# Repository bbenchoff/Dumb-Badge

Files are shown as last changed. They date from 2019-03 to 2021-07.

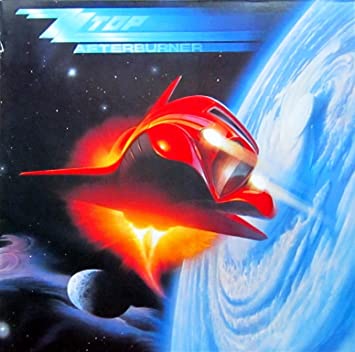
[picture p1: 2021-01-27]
Art-Assets/RandomGraphics/reference/Album Covers where guitars are spaceships/81FVQIFJtqL._SX355_.jpg

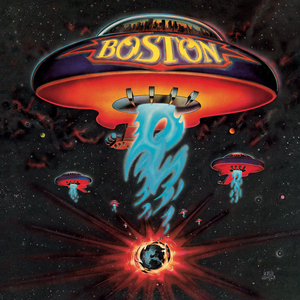
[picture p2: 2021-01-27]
Art-Assets/RandomGraphics/reference/Album Covers where guitars are spaceships/BostonBoston.jpg

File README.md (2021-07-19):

# VT-69 Portable Terminal

Front View Image

The VT-69 is a portable, battery-powered dumb terminal, along the lines of a VT-100, VT-220, Wyse WY-50, or other such microprocessor-controlled dumb terminals of the mid-80s to mid-90s. It's a portable shell, or a game console that only plays text-based adventures.

Features include:
* 4" LCD with 800x480 resolution
  * Display allows for a full 80x24 character display. *This is not a graphical display*. It will only display text characters.
  * 65536 colors, all of them.
* Silicone membrane keyboard
  * 69 keys. That's why it's the VT-69.
  * Custom-desinged, it's like the keypad on a remote control
  * Other keyboard layouts supported; DVORAK, QWERTZ, and AZERTY are simply a matter of keyboard legends.
* Battery power
  * Internal LiPo battery (> 2000 mAh) is charged from USB-C connector.
  * Provides > 12 hours of battery life.
* Microcontroller
  * ATSAMD51 clocked at blistering 120MHz
  * Custom software libraries allow for fastest text rendering possible	
* Connectivity
  * DE-9 RS-232 serial connector, provided with MAX3232
  * Serial output over USB-C connector
  * Internal UART connectors allow for internal connection to $Single Board Computer$ (a la VT-180) or any other development board with a 'standard' 40-pin header.
  * Hardware handshaking in both DE-9 RS-232 port and internal header
  * Supports _almost_ every terminal escape code recognized by the Linux console.
* Documentation
  * [Many pages of documentation](https://github.com/ViolenceWorks/VT-69/blob/main/Documentation/README.md)
  
Side View Image

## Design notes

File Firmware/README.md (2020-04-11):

## Install baremetal toolchain

`sudo apt-get install gcc-arm-none-eabi make git gcc libudev-dev`

[Download Microchip Advanced Software Framework](https://www.microchip.com/mymicrochip/filehandler.aspx?ddocname=en1000272) or you could [find the latest version here](https://www.microchip.com/mplab/avr-support/avr-and-sam-downloads-archive). Look for Advanced Software Framework (ASF) and grab the latest version. Unzip that somewhere.

This will allow you to compile the example program
\xdk-asf-3.48.0\sam0\applications\led_toggle\samd21_xplained_pro

Run make on that, should produce /samd21_xplained_pro/gcc/led_toggle_flash.bin

## Install edbg
[edbg](https://github.com/ataradov/edbg) is a tool for progamming ARM through Atmel edbg-based boards. Install that.

You can either clone it and do a `make all` or download the binary if you don't give a fuck about security.

This will produce a binary used to upload code

## Burn firmware

Test the led_toggle_flash.bin by uploading to SamD21 board with the following

`edbg -b -p -v -f led_toggle_flash.bin -t atmel_cm0p`

The toolchain and uploading has been verified on your machine. Now we need a makefile and such for the real code.

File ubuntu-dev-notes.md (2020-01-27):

Building Dumb Badge on Unbuntu -- for Idiots
===
```
sudo apt-get install gcc-arm-none-eabi binutils-arm-none-eabi gdb-arm-none-eabi openocd
```

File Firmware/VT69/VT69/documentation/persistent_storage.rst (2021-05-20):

Persistent Storage
==================

Persistent storage is middle-ware which provides means for storing data in non-volatile memory.

In terms of persistent storage stored data is called an item. Different items must have different IDs. IDs must be unique
and start with value of 1.
If an item is written two or more times, previous values get "overwritten" (read access returns the latest written data).

The usual use-case of persistent storage is an attempt to restore previously stored items on start-up.
For that, nv_storage_init function must be called. This function scans non-volatile memory starting from the given address
looking for items to restore. If there is a valid storage, the persistent storage initializes internal structures and gets
prepared for upcoming read (or write) accesses. If no valid storage found, the persistent storage tries to create one by
writing a header with storage information.

When an item is written the first item, it is being created inside the storage. In this case "offset" parameter is
ignored and the item is created with the given size. Re-sizing of items is not allowed, attempts to write more data than
item size or outside of an item (offset + size in write access is bigger than initial size) will fail.

Features
--------

* Power failure protection
* Wear-leveling
* Writing/reading parts of stored items
* Possibility to work with different types of non-volatile memory

Architecture and provided functionality
---------------------------------------

The persistent storage is composed of two layers:

* NV storage

This is the upper layer which contains implementation of wear-leveling, partial write and power failure protection
algorithms.

The partial write/read access allows to write/read parts of previously written items. For example, it is possible to read
first N bytes, or last N bytes, or N bytes from the middle of stored item.
Read operation always returns the latest successfully written data, it applies for partial write too. For example, if
partial write access stores M first bytes of the item of length of N (N > M), then read operation returns data that
contains M first bytes from partial write, and N-M last bytes from initial write.

The writing of an item or its part is split into three write accesses, after each it is validated whether the data was
written correctly by reading it out and comparing with the content of an item in RAM. It is required to be able to detect
whether data was written correctly if a power failure happens during writing procedure. This detection happens during
storage initialization (nv_storage_init function). In case of detection of invalid item, previous successfully written
item, if any, is used.

The area in non-volatile memory allocated for the persistent storage is split to at least (by default) two sectors.
Each write operation writes data to a new position in one of the sectors, gradually filling it up. When the sector is
full, the persistent storage can detect this fact during write/delete access. Upon detection, before actual write,
sector compression is performed. During the compression each of the stored items is gathered into one item (if there were
partial writes accesses) and copied to another sector. After all the items are copied, new sector is activated and
previous sector is erased.
The level of wearing non-volatile memory out can be tuned by adjusting the size of the area allocated for the persistent
storage.

Usually writing to non-volatile memory is a slow process, the sector compression may take significant time. The persistent
storage provides function (nv_storage_force_packing) to allow applications to perform the compression at the time suitable
for the application.

* Wrapper

This is the lower layer which is basically a wrapper between API expected by the upper layer and driver/middle-ware used
to work with non-volatile memory. At the moment, only internal flash on SAMD/SAML/SAMR/SAMC devices is supported.

Dependencies
------------

Flash driver on SAMD/SAML/SAMR/SAMC devices.

Limitations
-----------

Due to the architecture of the flash memory on SAMD/SAML/SAMR/SAMC devices, which allows only 8 writes before flash row
must be erase for the next write, each write of an item or a part of an item is aligned by 128 bytes.

Currently only internal flash memory on SAMD/SAML/SAMR/SAMC devices is supported.
It is user's responsibility to modify the linker script to reserve section in flash for the storage. Its start address
should match the address provided in the persistent storage configuration, its size should be equal to the sector size
multiplied by sectors amount (2 by default).

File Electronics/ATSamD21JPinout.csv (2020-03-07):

ATSAMD21J18A | Pin # | Function | ATSAMD21J | Pin # | Function
PA00 | 1 | XIN32 | PB00 | 61 | LCD 00
PA01 | 2 | XOUT32 | PB01 | 62 | LCD 01
PA02 | 3 | KEWROW0 | PB02 | 63 | LCD 02
PA03 | 4 | KEYROW01 | PB03 | 64 | LCD 03
PA04 | 13 | KEYROW02 | PB04 | 5 | LCD 04
PA05 | 14 | KEYROW03 | PB05 | 6 | LCD 05
PA06 | 15 | KEYROW04 | PB06 | 9 | LCD 06
PA07 | 16 | KEYROW05 | PB07 | 10 | LCD 07
PA08 | 17 | UART_TX | PB08 | 11 | LCD 08
PA09 | 18 | UART_RX | PB09 | 12 | LCD 09
PA10 | 19 | KEYROW06 | PB10 | 23 | LCD 10
PA11 | 20 | KEYROW07 | PB11 | 24 | LCD 11
PA12 | 29 | KEYROW08 | PB12 | 25 | LCD 12
PA13 | 30 | KEYROW09 | PB13 | 26 | LCD 13
PA14 | 31 |  | PB14 | 27 | LCD 14
PA15 | 32 |  | PB15 | 28 | LCD 15
PA16 | 35 | KEYCOLUMN0 | PB16 | 39 | LCD_RW
PA17 | 36 | KEYCOLUMN1 | PB17 | 40 | LCD_W/R
PA18 | 37 | KEYCOLUMN2
PA19 | 38 | KEYCOLUMN3
PA20 | 41 | KEYCOLUMN4
PA21 | 42 | KEYCOLUMN5
PA22 | 43 | SERCOM3 Pad0 | PB22 | 49 | LCD_CS
PA23 | 44 | SERCOM3 Pad1 | PB23 | 50 | LCD_D/C
PA24 | 45 | USB D-
PA25 | 46 | USB D+
PA27 | 51 | KEYCOLUMN6
PA28 | 53
PA30 | 57 | SWD Clock | PB30 | 59 | LCD_RST
PA31 | 58 | SWD data | PB31 | 60 | 3.3VFromPi

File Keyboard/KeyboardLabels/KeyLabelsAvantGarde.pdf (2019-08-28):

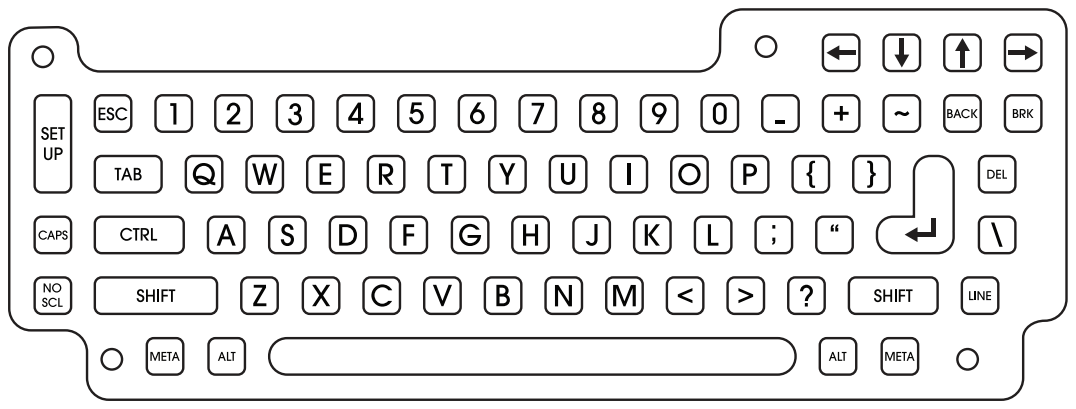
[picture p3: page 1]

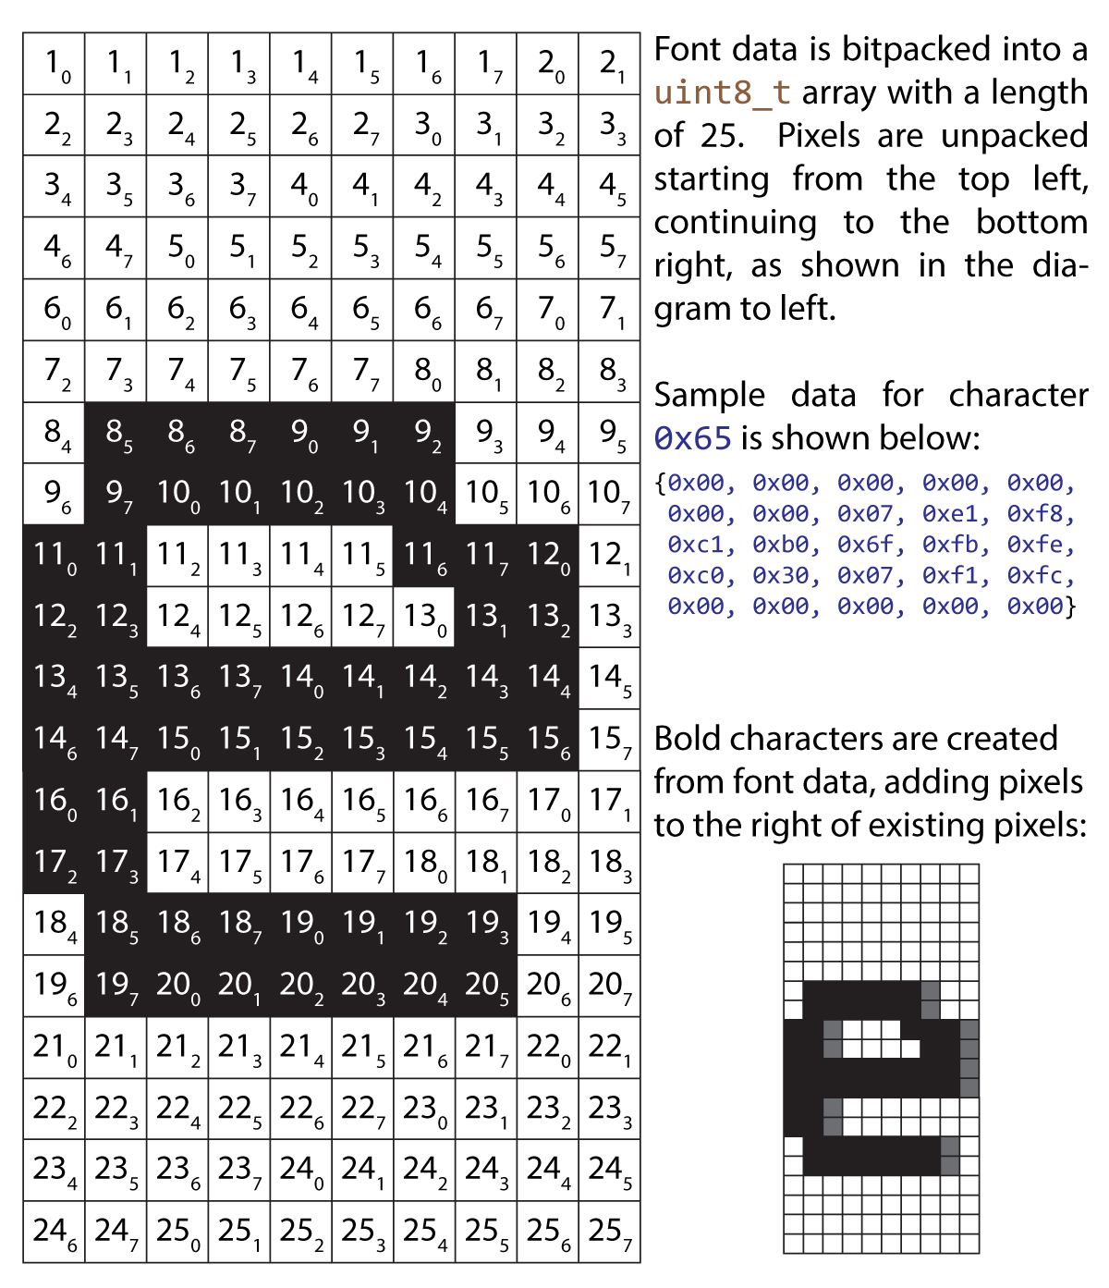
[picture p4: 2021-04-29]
Art-Assets/Documentation/FontDiagram.png

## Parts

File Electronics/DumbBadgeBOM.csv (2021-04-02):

Item # | Quantity | Reference Des. | Description / Value | MFG Part # | LCSC Part # | Package | Description | Pads | Qty |  | LABEL01 | LABEL02 | LABEL03 | LABEL04 | LABEL05 | LABEL06 | LABEL07 | LABEL08 | LABEL09 | LABEL10 | MANUFACTURER_NAME | MANUFACTURER_PART_NUMBER | MF | MOUSER_PART_NUMBER | MOUSER_PRICE-STOCK | MPN | OC_FARNELL | OC_NEWARK | POPULARITY | POPULATE | PROD_ID | SPICEPREFIX | TP_SIGNAL_NAME | URL | VALUE
1 | 1 | B1 | DNP | DNP | DNP | DNP | DNP
2 | 6 | C1, C4, C9, C22-24 | 0.1uF | C0805B104K500NT | C476766 | 0805-NO | 1ÂµF ceramic capacitors | 2 |  | 12 |  |  |  |  |  |  |  |  |  |  |  |  |  |  |  |  |  |  |  |  | CAP-08064 |  |  |  | 1.0uF
3 | 3 | C2, C7, C8, C14 | 10uF | CL21A106KPFNNNE | C17024 | 0805-NO | 1ÂµF ceramic capacitors | 2 |  | 6 |  |  |  |  |  |  |  |  |  |  |  |  |  |  |  |  |  |  |  |  | CAP-08064 |  |  |  | 1.0uF
4 | 1 | C3 | 2.2uF | GRM219R71C225KE15D | C86034 | 0805-NO | 1ÂµF ceramic capacitors | 2 |  | 2 |  |  |  |  |  |  |  |  |  |  |  |  |  |  |  |  |  |  |  |  | CAP-08064 |  |  |  | 1.0uF
5 | 4 | C5, C10, C11, C13 | 1.0uF | CL21B105KBFNNNE | C28323 | 0805-NO | 1ÂµF ceramic capacitors | 2 |  | 8 |  |  |  |  |  |  |  |  |  |  |  |  |  |  |  |  |  |  |  |  | CAP-08064 |  |  |  | 1.0uF
6 | 1 | C6 | 100uF | JMK325BJ107MM-T | C191180 | 1210 | CAPACITOR, American symbol | 2 |  | 2 |  |  |  |  |  |  |  |  |  |  |  |  |  |  |  |  |  |  | 6 |  |  | C
8 | 1 | C15 | 1uF | CL10A105KO8NNNC | C1592 | 0603-NO | Ceramic Capacitors | 2 |  | 2
9 | 10 | C16-C21, C25, C28-31 | .1u | 06035G104ZAT2A | C143639 | 0603-NO | Ceramic Capacitors | 2 |  | 20
10 | 2 | C26, C27 | 22pF | 0805CG220J500NT | C24658 | 0805-NO | 1ÂµF ceramic capacitors | 2 |  | 4 |  |  |  |  |  |  |  |  |  |  |  |  |  |  |  |  |  |  |  |  | CAP-08064 |  |  |  | 1.0uF
11 | 1 | D1 | MM3Z24VT1G | MM3Z24VT1G | C463816 | SOD323-W | DIODE | 3 |  | 3
12 | 1 | D2 | MBR0540 | MBR0540 | C232833 | SOD-123 | Diode | 3 |  | 3
13 | 1 | DE9FEMALE | DNP | EDGEMOUNTDE9 |  |  |  |  |  | 0
14 | 1 | FPC50CONN | 50PINFPC | Amphenol ICC / FCI 62684-501100ALF | C180244 | 62684-501100ALF |  | 52 |  | 52
15 | 1 | IC1 | ATSAMD51N19A-AU | ATSAMD51N19A-AU |  | QFP50P1600X1600X120-100N | ARM Microcontrollers - MCU 120MHZ 512KB FLASH 1 00 TQFP PKG 85C | 100 |  | 100 |  |  |  |  |  |  |  |  |  |  | Microchip | ATSAMD51N19A-AU |  | 556-ATSAMD51N19AAU | https://www.mouser.co.uk/ProductDetail/Microchip-Technology-Atmel/ATSAMD51N19A-AU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
16 | 1 | L1 | 6.8uH | TDK VLS5045EX-6R8M | C434837 | INDUCTOR_5X5MM_TDK_VLC5045 | Inductors | 2 |  | 2
17 | 1 | L2 | 6.8uH power L CID 2276 | Würth Elektronik 74404052068 |  | INDUCTOR_5X5MM_NR5040_NOTHERMALS | Inductors | 2 |  | 2
18 | 1 | L3 | 10uH | Taiyo Yuden CBC2518T100K | C271756 | INDUCTOR_1007 | Inductors | 2 |  | 2
19 | 3 | LED1, LED2, LED3 | LOW BATT | 17-21SURC/S530-A3/TR8 | C72037 | 0805-NO | LED | 2 |  | 6
20 | 2 | R1, R15 | 10k | 0603WAJ0103T5E | C15401 | 0603-NO | 1kÎ© resistor | 2 |  | 4 |  |  |  |  |  |  |  |  |  |  |  |  |  |  |  |  |  |  |  |  | RES-07856 |  |  |  | 1k
21 | 2 | R2, R3 | 5.1k | CR0603J5K10P05Z | C881139 | 0603-NO | 1kÎ© resistor | 2 |  | 4 |  |  |  |  |  |  |  |  |  |  |  |  |  |  |  |  |  |  |  |  | RES-07856 |  |  |  | 1k
22 | 2 | R4, R8 | 1.87M | 0603WAF1874T5E | C61679 | 0603-NO | 1kÎ© resistor | 2 |  | 4 |  |  |  |  |  |  |  |  |  |  |  |  |  |  |  |  |  |  |  |  | RES-07856 |  |  |  | 1k
23 | 1 | R5 | NCP21XW153J03RA | NCP21XW153J03RA | C152578 | 0805-NO | Resistors | 2 |  | 2
24 | 2 | R6, R13 | 200k | CQ03WAJ0204T5E | C966595 | 0603-NO | 1kÎ© resistor | 2 |  | 4 |  |  |  |  |  |  |  |  |  |  |  |  |  |  |  |  |  |  |  |  | RES-07856 |  |  |  | 1k
25 | 1 | R7 | 340k | 0603WAF3403T5E | C23143 | 0603-NO | 1kÎ© resistor | 2 |  | 2 |  |  |  |  |  |  |  |  |  |  |  |  |  |  |  |  |  |  |  |  | RES-07856 |  |  |  | 1k
26 | 1 | R9 | 270k | 0603WAJ0274T5E | C20088 | 0603-NO | 1kÎ© resistor | 2 |  | 2 |  |  |  |  |  |  |  |  |  |  |  |  |  |  |  |  |  |  |  |  | RES-07856 |  |  |  | 1k
27 | 2 | R10, R17 | 100k | 0603WAJ0104T5E | C15458 | 0603-NO | 1kÎ© resistor | 2 |  | 4 |  |  |  |  |  |  |  |  |  |  |  |  |  |  |  |  |  |  |  |  | RES-07856 |  |  |  | 1k
28 | 4 | R11, R14, R16, R20 | 1k | RC0603JR-071KL | C14676 | 0603-NO | 1kÎ© resistor | 2 |  | 8 |  |  |  |  |  |  |  |  |  |  |  |  |  |  |  |  |  |  |  |  | RES-07856 |  |  |  | 1k
29 | 1 | R12 | 6 Ohm | RC0603FR-076R04L | C482889 | 0603-NO | 1kÎ© resistor | 2 |  | 2 |  |  |  |  |  |  |  |  |  |  |  |  |  |  |  |  |  |  |  |  | RES-07856 |  |  |  | 1k
30 | 1 | SW1 | SPST_TACT-KMR2 | KMR221GLFS | C72443 | KMR2 | SMT 6mm switch, EVQQ2 series | 4 |  | 4
31 | 1 | T1 | MMUN2133LT1G | ON Semiconductor MMUN2133LT1G | C86182 | SC59-BEC | PNP Bias Resistor Transistor | 3 |  | 3
32 | 1 | U$5 | DNP | DNP |  | DNP |  |  |  | 0
33 | 1 | U$30 | DNP | DNP |  | DNP |  |  |  | 0
34 | 1 | U2 | TPS61090RSAR | Texas Instruments TPS61090RSAR | C206167 | PVQFN-16 | TPS6103x 4A Boost - 1.8-5.5V Input, Adjustable Output to 5.5V | 16 |  | 16
35 | 1 | U3 | MCP73871 | Microchip MCP73871-2CCI/ML | C511310 | QFN20_4MM | MCP73871 Lithium Polymer Battery Charger | 20 |  | 20
36 | 1 | U4 | FAN5333BSX | FAN5333BSX | C457660 | SOT23-5@1 | FAN5331 - LED/OLED 20V Boost Converter | 5 |  | 5
37 | 1 | U5 | TPD3E001SOT5 | TPD3E001DRLR | C470828 | SOT(5) |  | 5 |  | 5
38 | 1 | U6 | MAX3232 | MAX3232ECDR | C414613 | SO16 | RS232 Transceiver | 16 |  | 16 |  |  |  |  |  |  |  |  |  |  |  |  |  |  |  |  |  |  |  |  | IC-08171 |  |  |  | MAX3232
39 | 1 | USB | TYPE-C-31-M-12 | TYPE-C-31-M-12 | C165948 | TYPE-C-31-M-12 |  | 12 |  | 12
40 | 1 | VREG | REG1117 | REG1117A |  | SOT223 | 800mA and 1A Low Dropout (LDO) Positive Regulator | 4 |  | 4 |  |  |  |  |  |  |  |  |  |  |  |  |  |  |  | REG1117 | 1097566 | 14P6981 | 49
41 | 1 | X1 | NX3215SA-32.768K-STD-MUA-8 | S3132768092070 | C479190 | XTAL3215 | Low cost SMT crystals, no capacitors included | 2 |  | 2
42 | 1 | X2 | DNP | DNP |  | DNP | DUAL ROW STRAIGHT HEADER 1364 SERIES. 1.27mm x 1.27mm. Without Fixing Post. SMT |  |  | 0 |  |  |  |  |  |  |  |  |  |  |  |  |  |  |  |  | unknown | unknown
 |  |  |  |  |  |  |  |  |  | 0
 |  |  |  |  |  |  |  |  |  | 349

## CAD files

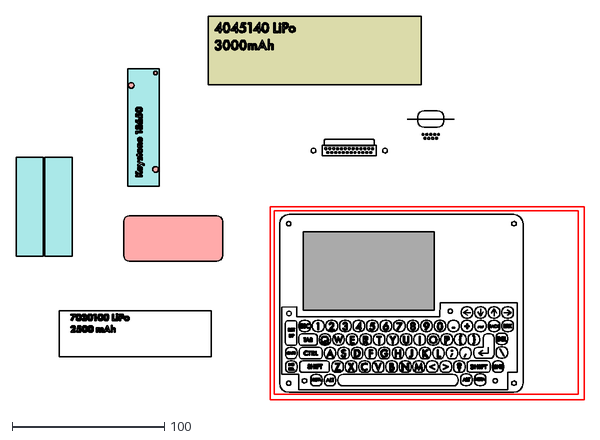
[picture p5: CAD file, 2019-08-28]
Keyboard/Vectors/SiliconeComplete.dxf
373.3 x 252.3

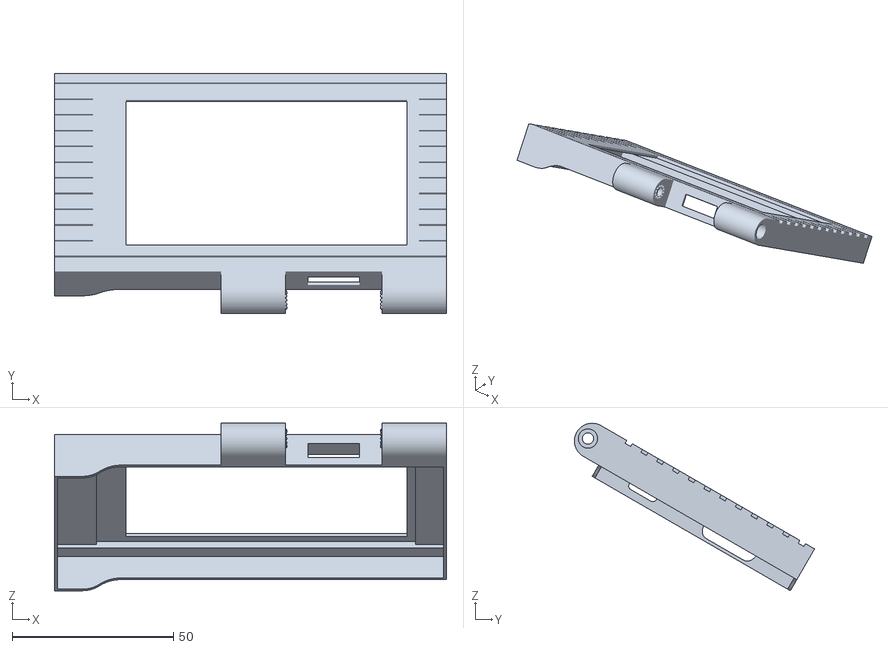
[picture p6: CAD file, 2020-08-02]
Extensions/FoldingKeyboardTest/ScreenHolder.stl
121.6 x 74.5 x 52.0

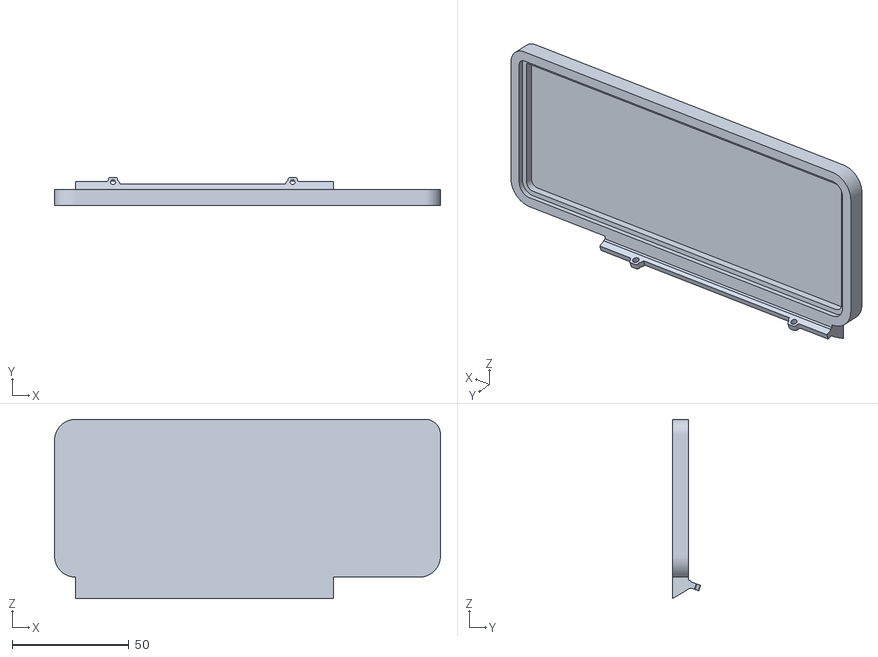
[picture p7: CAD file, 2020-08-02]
Extensions/MCUDemoBoard/KeyboardandMCU.stl
165.5 x 12.2 x 76.9

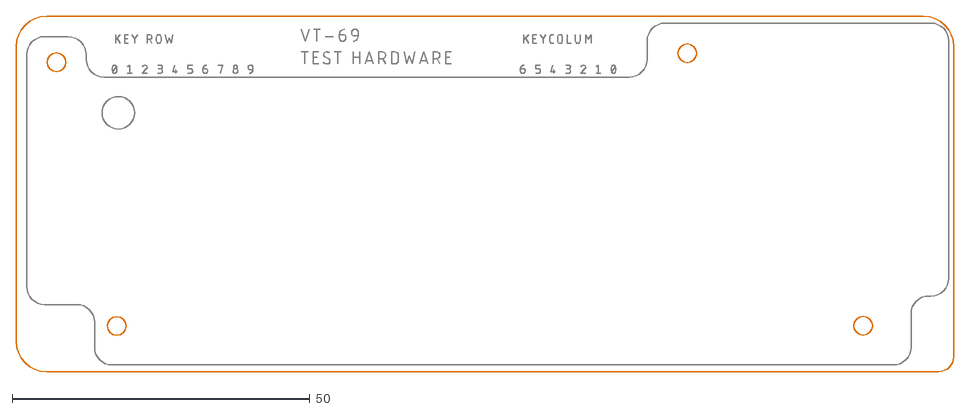
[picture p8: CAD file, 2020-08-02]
Extensions/TestKeyboard/Keyboard.dxf
157.5 x 59.7

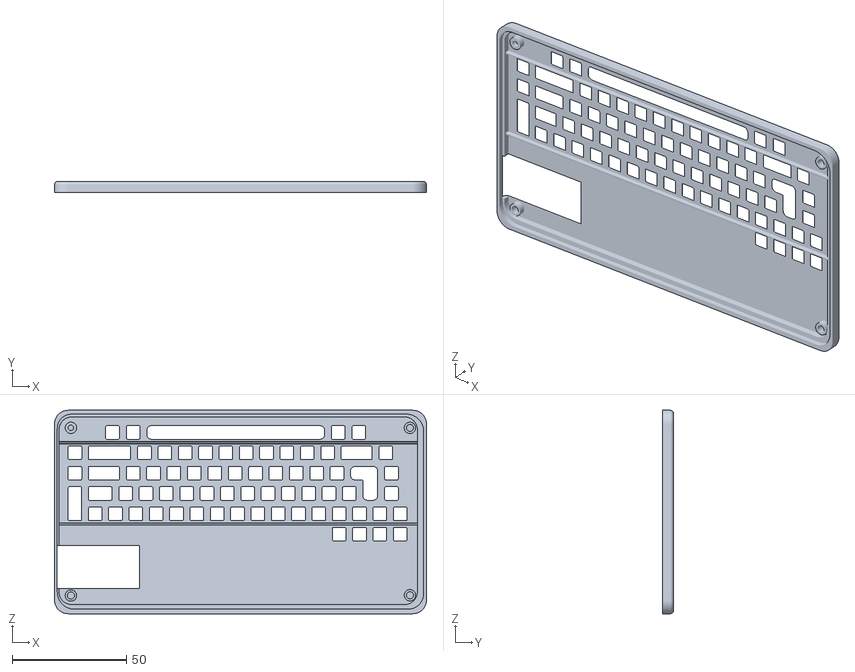
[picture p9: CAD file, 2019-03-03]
Keyboard/TestKeyboard/Hardware/KeyboardSTL.stl
162.6 x 5.00 x 88.9

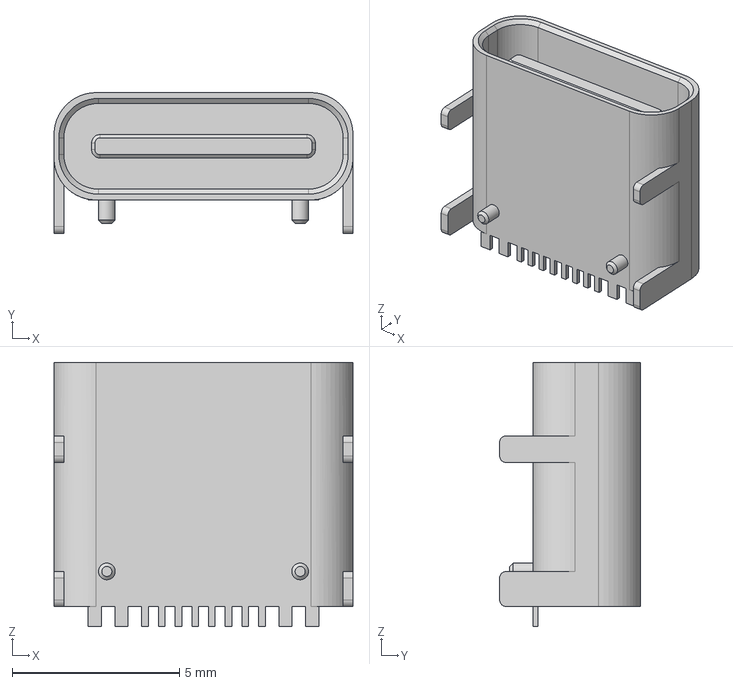
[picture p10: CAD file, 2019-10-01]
Mechanical/Models/HRO TYPE-C-31-M-12.step
8.94 x 4.21 x 7.90 mm

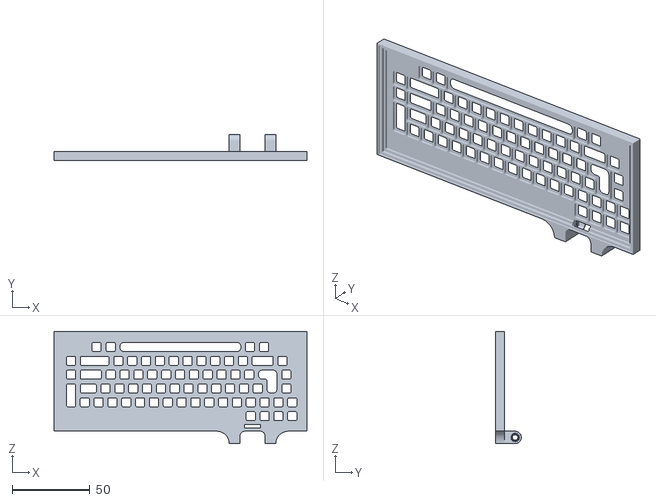
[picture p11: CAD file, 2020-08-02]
Extensions/FoldingKeyboardTest/Keyboard.stl
162.6 x 16.6 x 72.2

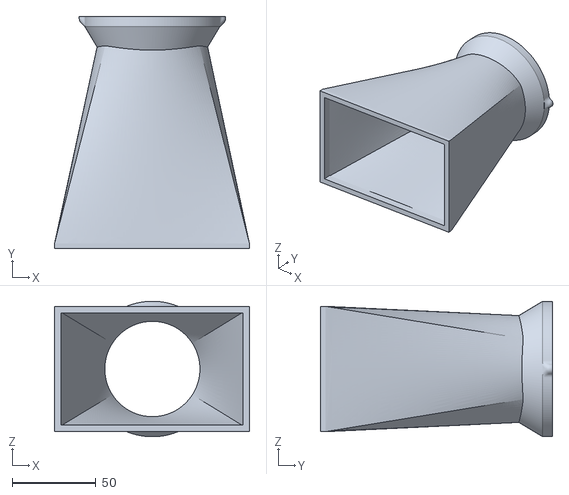
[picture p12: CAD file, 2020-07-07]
Extensions/MCUDemoBoard/CameraMountAdapter.stl
116.6 x 139.0 x 81.0

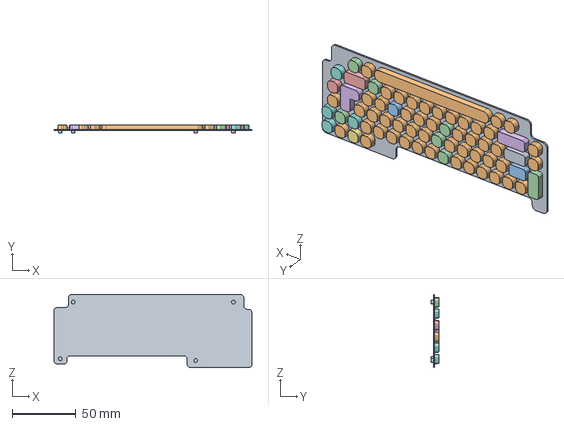
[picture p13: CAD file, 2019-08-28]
Mechanical/Models/Silicone Keyboard.step
154.9 x 6.50 x 57.1 mm

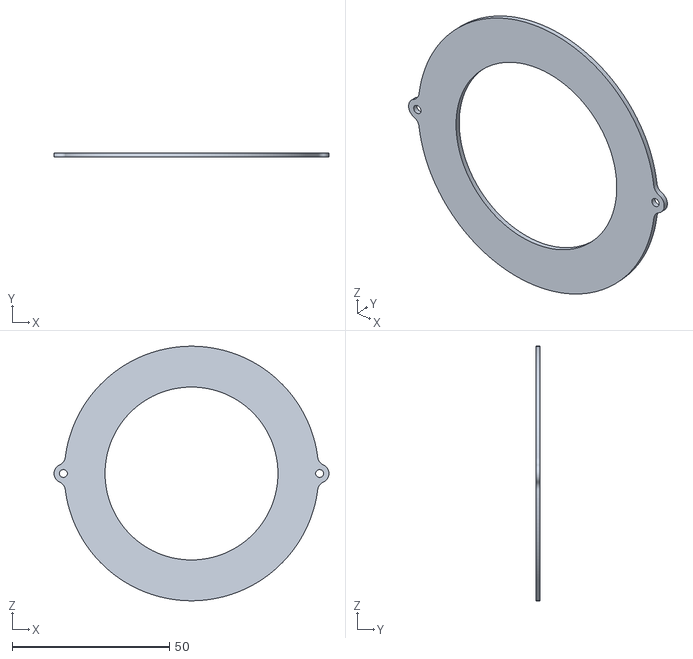
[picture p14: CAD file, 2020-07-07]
Extensions/MCUDemoBoard/CameraMountAdapterBack.stl
87.5 x 1.40 x 81.0

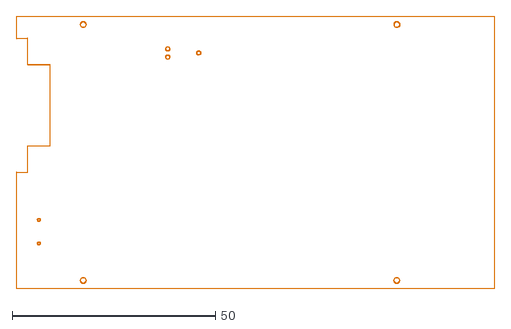
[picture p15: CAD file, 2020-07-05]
Extensions/MCUDemoBoard/MCUDemoBoard.dxf
117.8 x 67.2

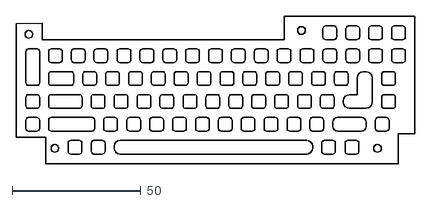
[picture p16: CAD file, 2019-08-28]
Keyboard/Vectors/SmallerSiliconeOutlineComposite.dxf
154.9 x 57.1

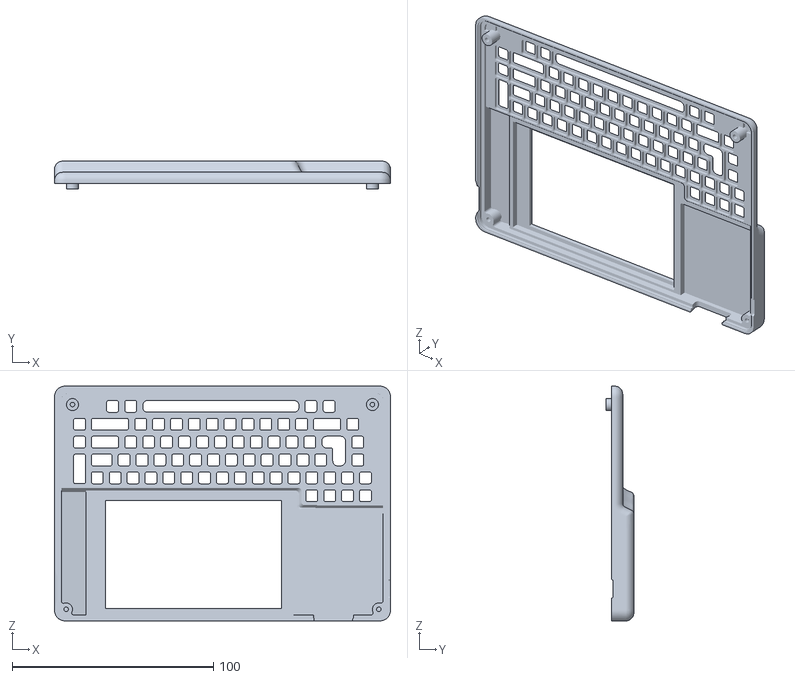
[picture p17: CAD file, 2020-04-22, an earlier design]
Mechanical/Top.stl
167.1 x 13.8 x 116.8

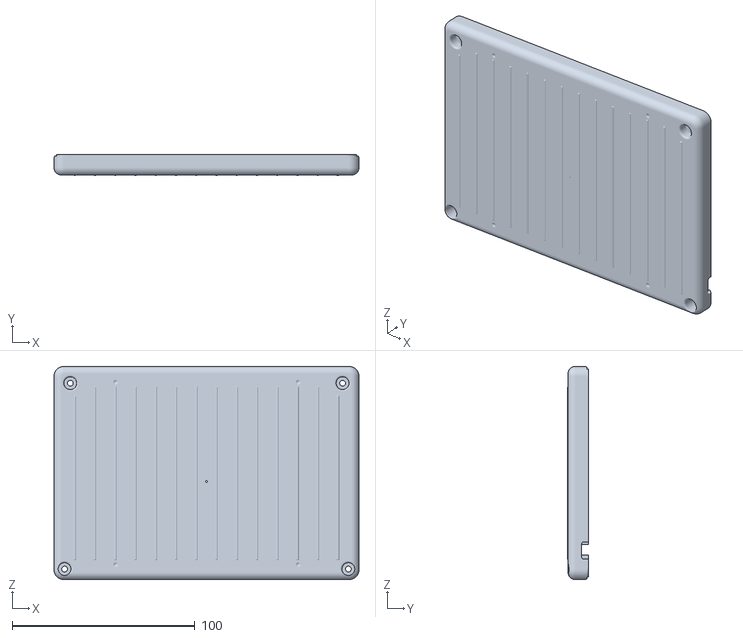
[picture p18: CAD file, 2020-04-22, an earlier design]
Mechanical/Bottom.stl
167.1 x 11.6 x 116.8

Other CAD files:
Keyboard/Vectors/DumbBadgeButtonsOutline.dxf
Keyboard/Vectors/DumbBadgeSiliconeOutline.dxf
Mechanical/Models/Bottom.stl
Mechanical/Models/Top.stl

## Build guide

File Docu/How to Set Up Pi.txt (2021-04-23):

1) first enable serial in raspi-update

blah blah blah just pick the option

2) edit the serial-getty service

sudo nano /lib/systemd/system/serial-getty@.service

change to this:

[Serivce]
ExecStart=-/sbin/agetty 9600 %I vt100

3) restart the systemctl

systemctl daemon-reload

---------------------------------------------------
ENABLE Shell messages on the serial console

from the console, type:
>sudo raspi-config

Select option P6, Serial Port

Select Yes. You would like a login shell to be accessible over serial.

2) edit the serial-getty service

> sudo nano /lib/systemd/system/serial-getty@.service

Change the line
> ExecStart=-/sbin/agetty -o '-p -- \\u' --keep-baud 115200,38400,9600 %I $TERM

to the following:

> ExecStart=-/sbin/agetty 9600 %I vt100

3) restart systemctl

> systemctl daemon-reload

4) reboot the system.

On reboot, you should see a stream of serial bits coming out of the GPIO pins. Eventually, you will be able to login

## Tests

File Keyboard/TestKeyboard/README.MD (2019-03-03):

This is the repo for the test/verification keyboard. It uses the same silicone keyboard, but *it's just a USB keyboard*

Included files are:

Firmware for Teensy LC
PCB for keyboard/Teensy LC
Plastic Bezel

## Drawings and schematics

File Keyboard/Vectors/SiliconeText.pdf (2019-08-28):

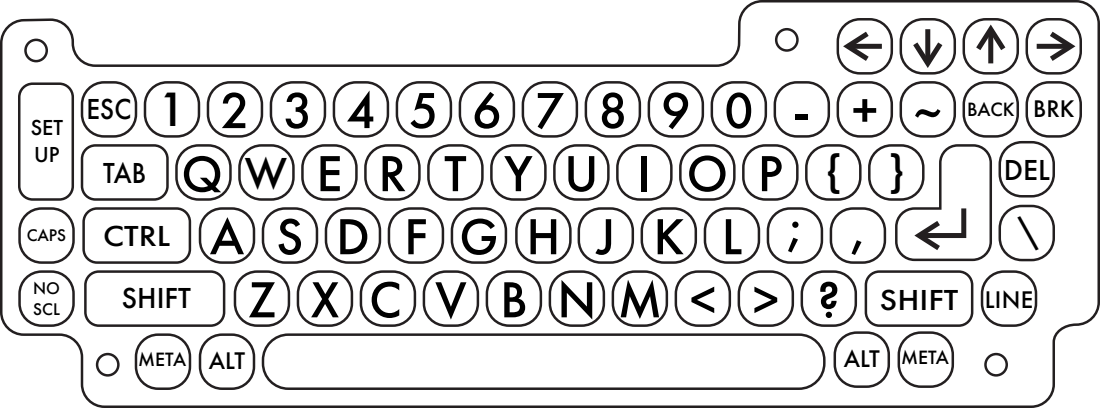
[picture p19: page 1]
1 2 3 4 5 6 7 8 9 0 - + ~ BACK; DEL \; TAB; CTRL A S D F G; SHIFT; Z X C V B N M < > ? SHIFT LINE; ESC; BRK; CAPS; NO SCL; SET UP; META ALT; ALT META

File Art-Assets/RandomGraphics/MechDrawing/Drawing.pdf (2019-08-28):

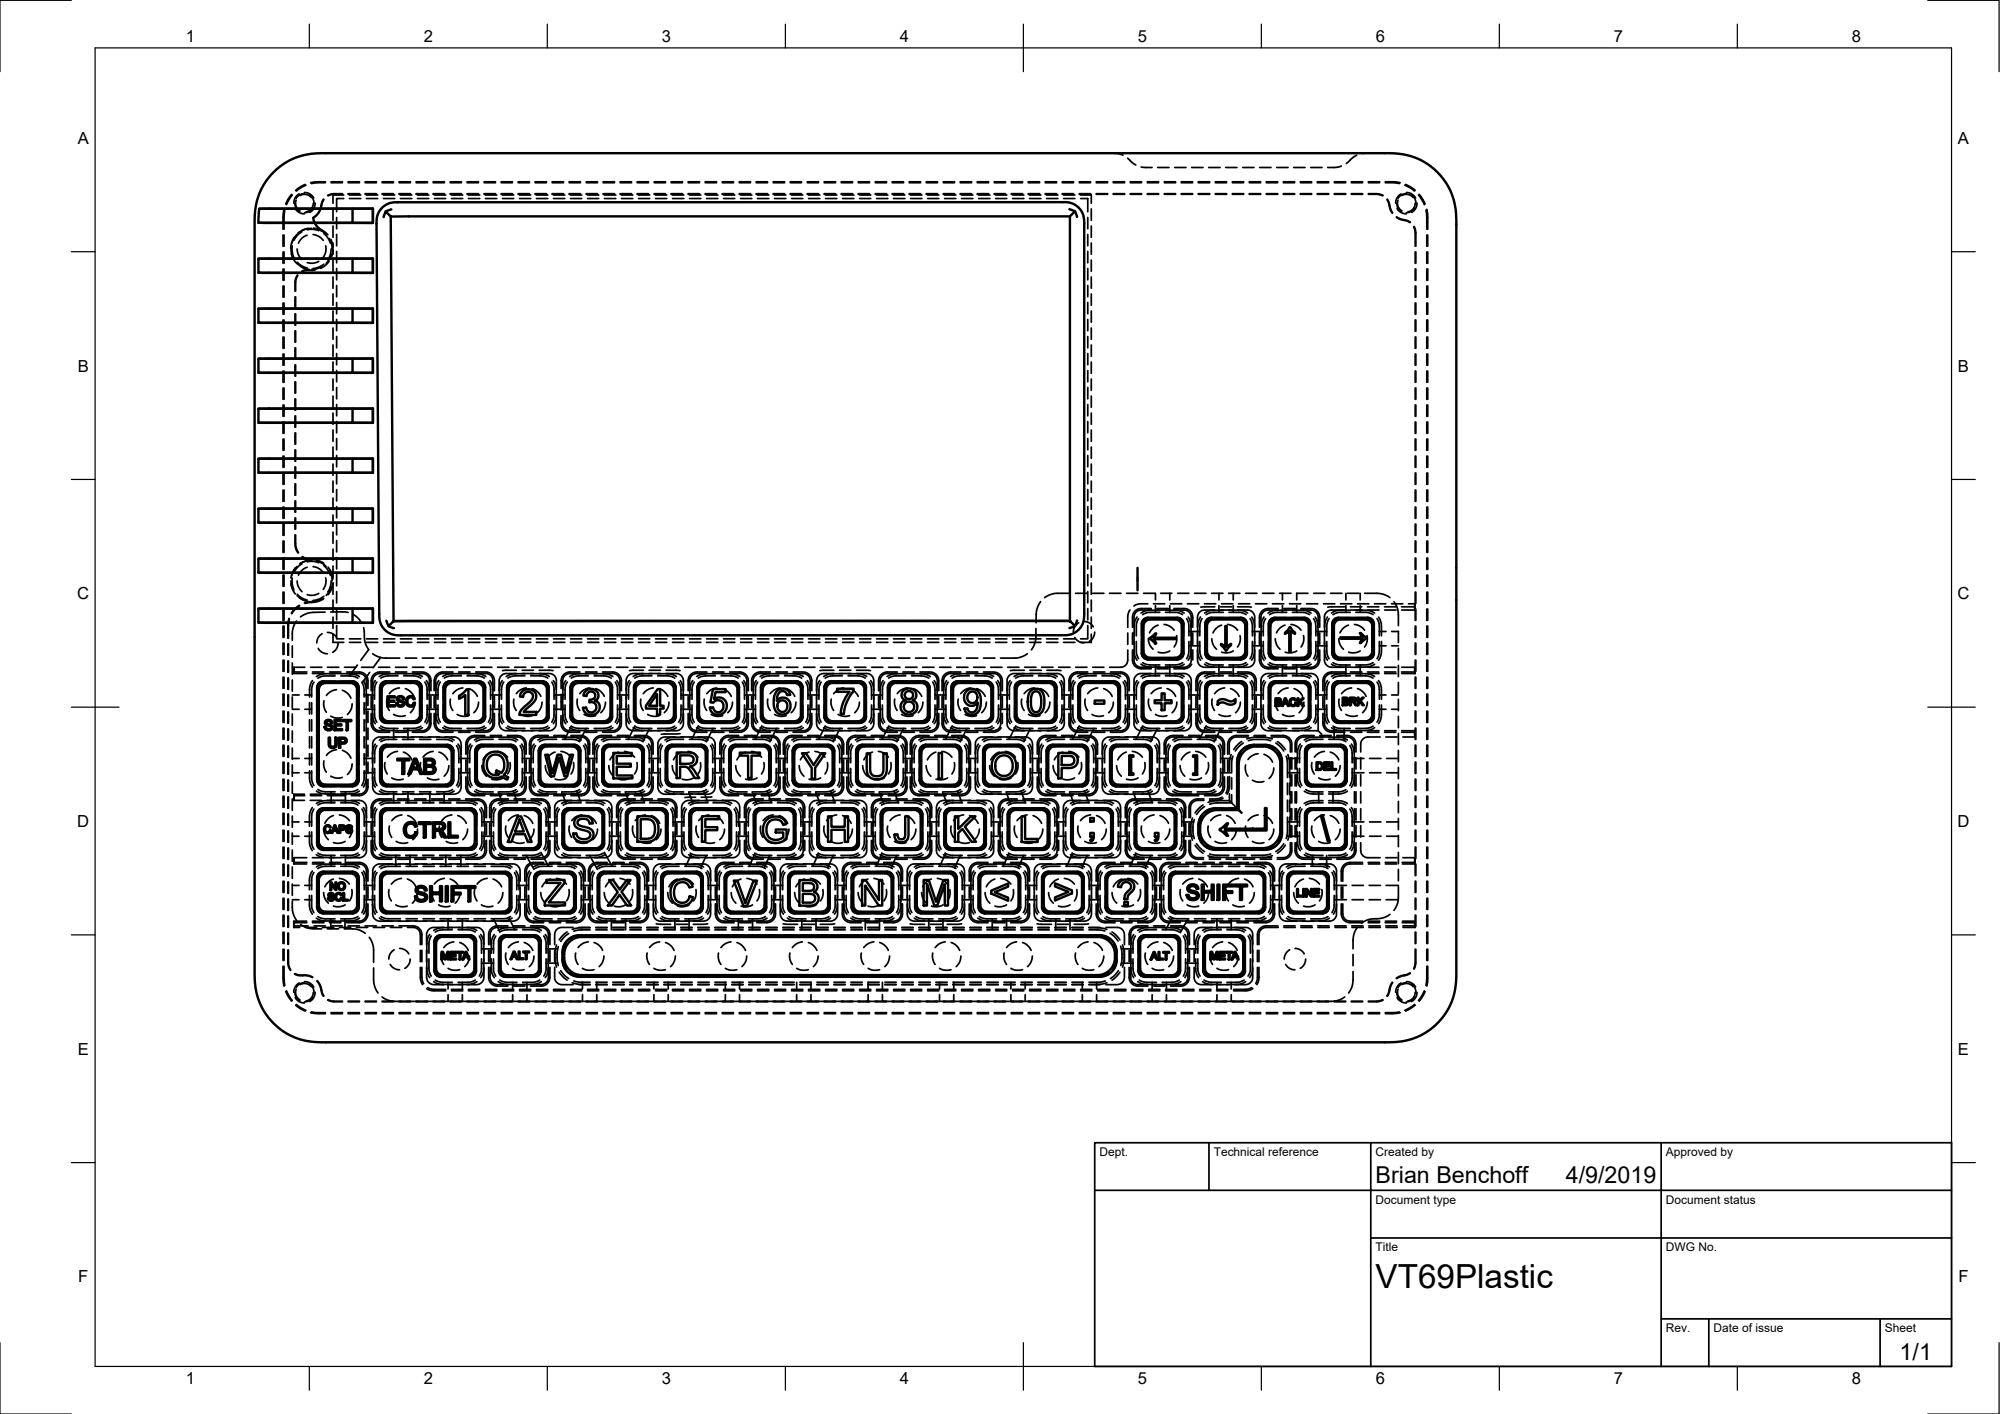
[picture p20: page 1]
Dept.; Technical reference; Created by; Approved by; Document type; Document status; Title; DWG No.; Rev.; Date of issue; Sheet; Brian Benchoff

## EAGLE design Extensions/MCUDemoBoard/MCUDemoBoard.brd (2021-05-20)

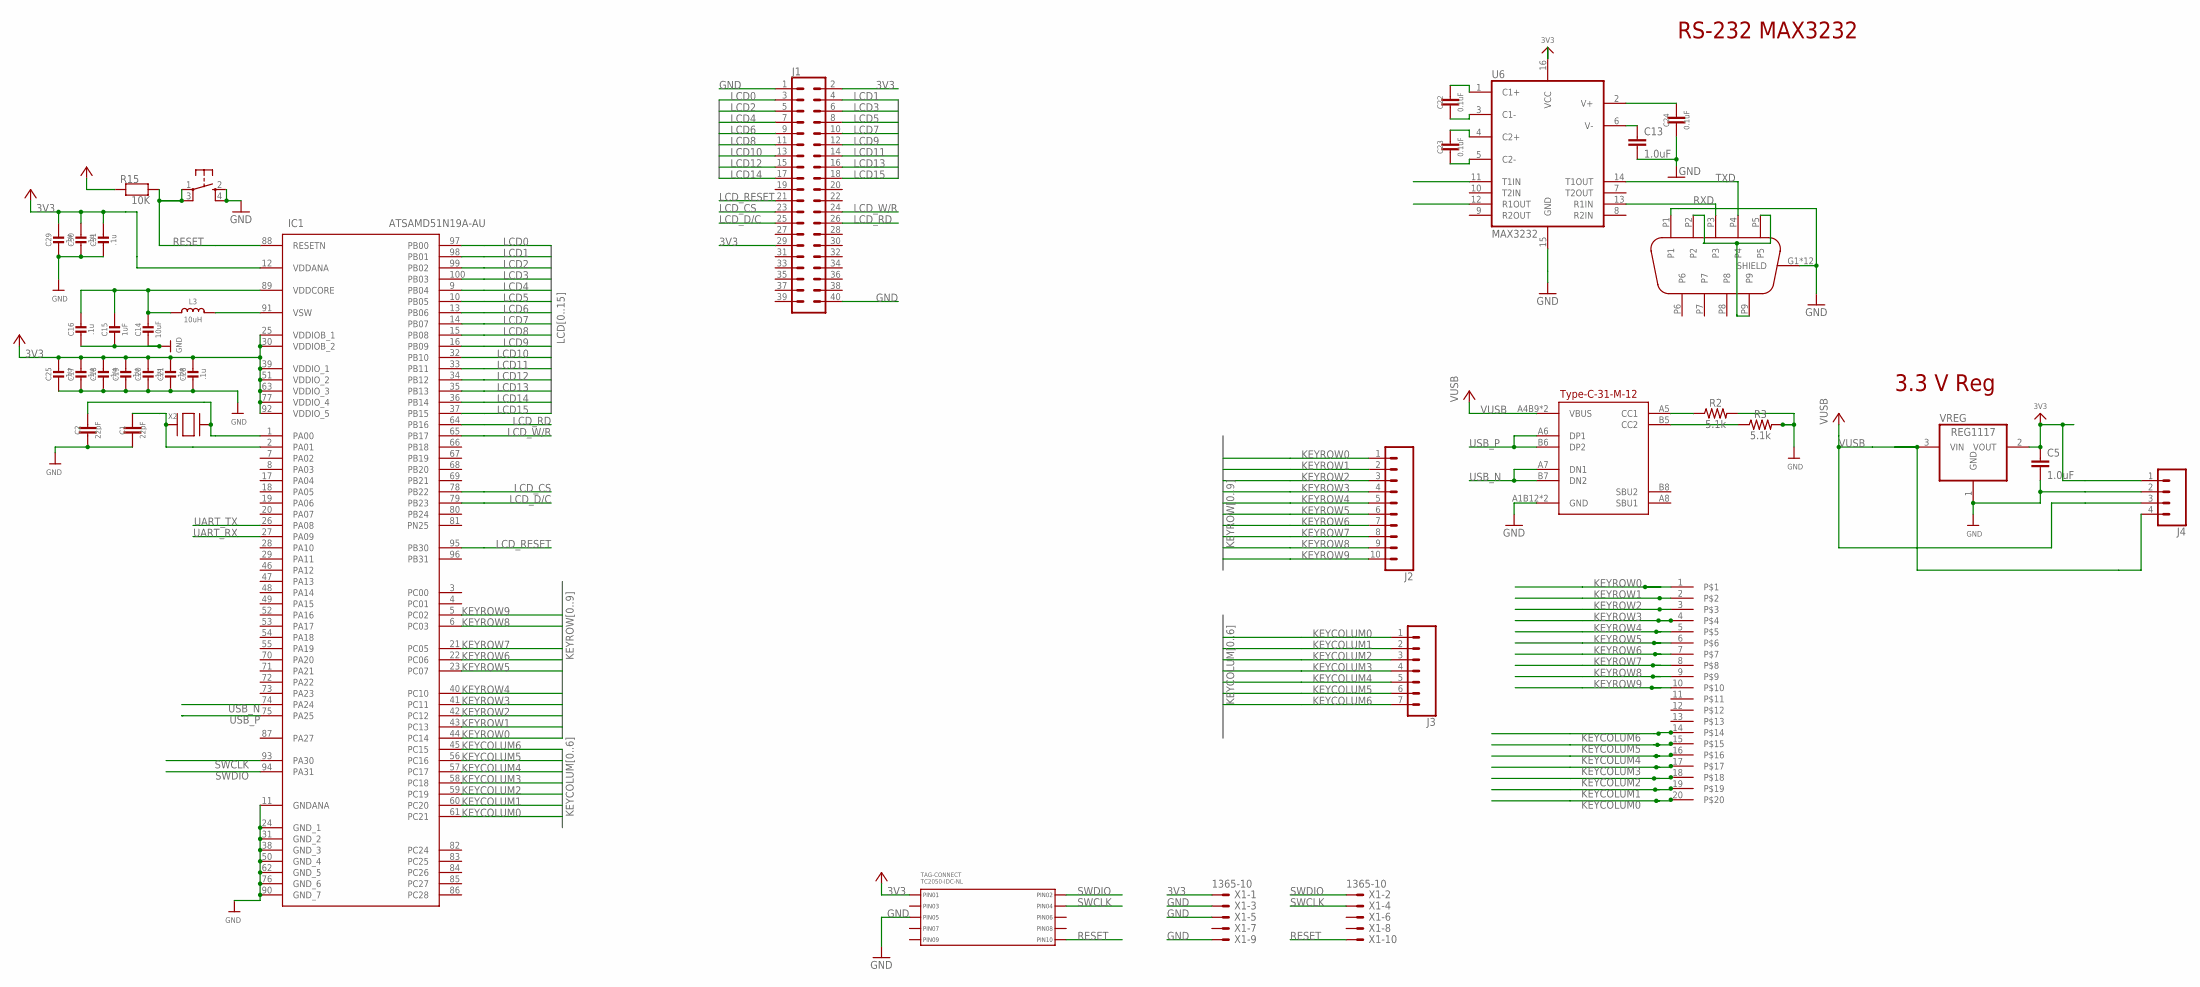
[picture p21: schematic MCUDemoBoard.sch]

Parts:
C1, C2: 22pF; 0805
C5, C13: 1.0uF; 0805
C14: 10uF; 0805-NO
C15: 1uF; 0603-NO
C16, C17, C18, C19, C20, C21, C25, C28, C29, C30, C31: .1u; 0603-NO
C22, C23, C24: 0.1uF; 0805
DE9FEMALE: EDGEMOUNTDE9; DE09S065TLF
IC1: ATSAMD51N19A-AU; QFP50P1600X1600X120-100N
J1: CONN_20X2NOSILK; 2X20_NOSILK
J2: CONN_10NO_SILK_PTH_FEMALE; 1X10_NO_SILK
J3: CONN_07NO_SILK; 1X07_NO_SILK
J4: CONN_04; 1X04
L3: 10uH; INDUCTOR_1007
R2, R3: 5.1k; 0603
R15: 10K; 0603-NO
SW2: SPST_TACT-KMR2; KMR2
TAG-CONNECT: TC2050-IDC-NL
U6: MAX3232; SO16
U$1: FC1-20-L2-T-WT20PIN; FC1-20-L2-T-WT
USB: TYPE-C-31-M-12
VREG: REG1117; SOT223
X1: 1365-10
X2: NX3215SA-32.768K-STD-MUA-8; XTAL3215

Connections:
3V3: C5.1, C17.2, C18.2, C19.2, C20.2, C21.2, C25.2, C28.2, C29.2, C30.2, C31.2, IC1.12 (VDDANA), IC1.25 (VDDIOB_1), IC1.30 (VDDIOB_2), IC1.39 (VDDIO_1), IC1.51 (VDDIO_2), IC1.63 (VDDIO_3), IC1.77 (VDDIO_4), IC1.92 (VDDIO_5), J1.2, J1.29, J4.1, R15.1, TAG-CONNECT.P$1 (PIN1), U6.16 (VCC), VREG.2 (VOUT), X1.1
GND: C1.1, C2.1, C5.2, C13.2, C14.2, C15.2, C16.1, C17.1, C18.1, C19.1, C20.1, C21.1, C24.2, C25.1, C28.1, C29.1, C30.1, C31.1, DE9FEMALE.G1 (SHIELD), DE9FEMALE.G2 (SHIELD), DE9FEMALE.G3 (SHIELD), DE9FEMALE.G4 (SHIELD), DE9FEMALE.G5 (SHIELD), DE9FEMALE.G6 (SHIELD), DE9FEMALE.G7 (SHIELD), DE9FEMALE.G8 (SHIELD), DE9FEMALE.G9 (SHIELD), DE9FEMALE.G10 (SHIELD), DE9FEMALE.G11 (SHIELD), DE9FEMALE.G12 (SHIELD), DE9FEMALE.P1, IC1.11 (GNDANA), IC1.24 (GND_1), IC1.31 (GND_2), IC1.38 (GND_3), IC1.50 (GND_4), IC1.62 (GND_5), IC1.76 (GND_6), IC1.90 (GND_7), J1.1, J1.40, J4.2, R2.2, R3.2, SW2.2 (S), SW2.4 (S1), TAG-CONNECT.P$5 (PIN5), U6.15 (GND), USB.A1B12 (GND), USB.B1A12 (GND), VREG.1 (GND), X1.3, X1.5, X1.9
KEYCOLUM0: IC1.61 (PC21), J3.1, U$1.20
KEYCOLUM1: IC1.60 (PC20), J3.2, U$1.19
KEYCOLUM2: IC1.59 (PC19), J3.3, U$1.18
KEYCOLUM3: IC1.58 (PC18), J3.4, U$1.17
KEYCOLUM4: IC1.57 (PC17), J3.5, U$1.16
KEYCOLUM5: IC1.56 (PC16), J3.6, U$1.15
KEYCOLUM6: IC1.45 (PC15), J3.7, U$1.14
KEYROW0: IC1.44 (PC14), J2.1, U$1.1
KEYROW1: IC1.43 (PC13), J2.2, U$1.2
KEYROW2: IC1.42 (PC12), J2.3, U$1.3
KEYROW3: IC1.41 (PC11), J2.4, U$1.4
KEYROW4: IC1.40 (PC10), J2.5, U$1.5
KEYROW5: IC1.23 (PC07), J2.6, U$1.6
KEYROW6: IC1.22 (PC06), J2.7, U$1.7
KEYROW7: IC1.21 (PC05), J2.8, U$1.8
KEYROW8: IC1.6 (PC03), J2.9, U$1.9
KEYROW9: IC1.5 (PC02), J2.10, U$1.10
LCD0: IC1.97 (PB00), J1.3
LCD1: IC1.98 (PB01), J1.4
LCD2: IC1.99 (PB02), J1.5
LCD3: IC1.100 (PB03), J1.6
LCD4: IC1.9 (PB04), J1.7
LCD5: IC1.10 (PB05), J1.8
LCD6: IC1.13 (PB06), J1.9
LCD7: IC1.14 (PB07), J1.10
LCD8: IC1.15 (PB08), J1.11
LCD9: IC1.16 (PB09), J1.12
LCD10: IC1.32 (PB10), J1.13
LCD11: IC1.33 (PB11), J1.14
LCD12: IC1.34 (PB12), J1.15
LCD13: IC1.35 (PB13), J1.16
LCD14: IC1.36 (PB14), J1.17
LCD15: IC1.37 (PB15), J1.18
LCD_CS: IC1.78 (PB22), J1.23
LCD_D/C: IC1.79 (PB23), J1.25
LCD_RD: IC1.64 (PB16), J1.26
LCD_RESET: IC1.95 (PB30), J1.21
LCD_W/R: IC1.65 (PB17), J1.24
unnamed: C24.1, U6.2 (V+)
unnamed: C2.2, IC1.1 (PA00), X2.P$1
unnamed: C1.2, IC1.2 (PA01), X2.P$2
unnamed: C22.2, U6.3 (C1-)
unnamed: C22.1, U6.1 (C1+)
unnamed: C23.1, U6.4 (C2+)
unnamed: C23.2, U6.5 (C2-)
unnamed: C13.1, U6.6 (V-)
unnamed: DE9FEMALE.P2, DE9FEMALE.P5, DE9FEMALE.P9
unnamed: R2.1, USB.A5 (CC1)
unnamed: R3.1, USB.B5 (CC2)
unnamed: C14.1, C15.1, C16.2, IC1.89 (VDDCORE), L3.P$1 (1)
unnamed: IC1.91 (VSW), L3.P$2 (2)
RESET: IC1.88 (RESETN), R15.2, SW2.1, SW2.3 (P1), TAG-CONNECT.P$10 (PIN10), X1.10
RXD: DE9FEMALE.P3, U6.13 (R1IN)
SWCLK: IC1.93 (PA30), TAG-CONNECT.P$4 (PIN4), X1.4
SWDIO: IC1.94 (PA31), TAG-CONNECT.P$2 (PIN2), X1.2
TXD: DE9FEMALE.P4, U6.14 (T1OUT)
UART_RX: IC1.27 (PA09), U6.12 (R1OUT)
UART_TX: IC1.26 (PA08), U6.11 (T1IN)
USB_N: IC1.74 (PA24), USB.A7 (DN1), USB.B7 (DN2)
USB_P: IC1.75 (PA25), USB.A6 (DP1), USB.B6 (DP2)
VUSB: J4.3, J4.4, USB.A4B9 (VBUS), USB.B4A9 (VBUS), VREG.3 (VIN)

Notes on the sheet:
RS-232 MAX3232
Type-C-31-M-12
3.3 V Reg

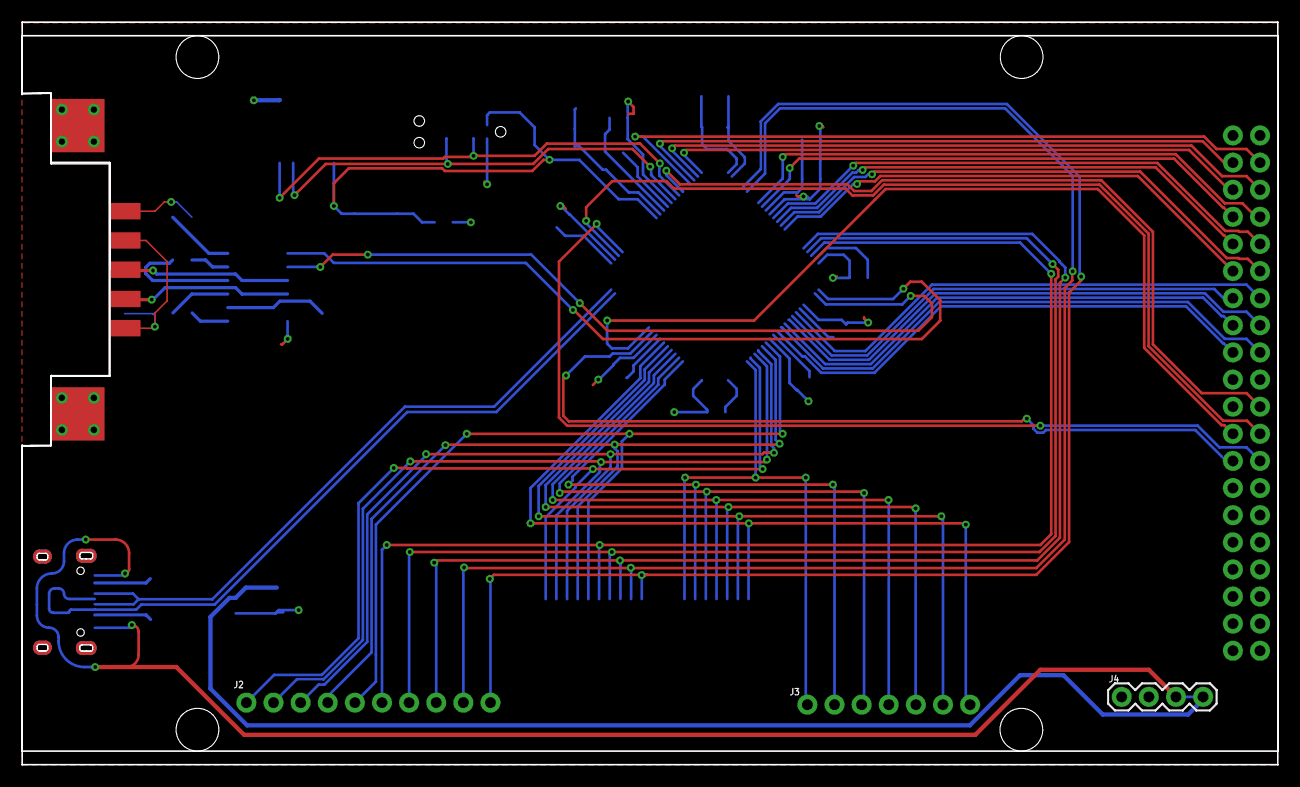
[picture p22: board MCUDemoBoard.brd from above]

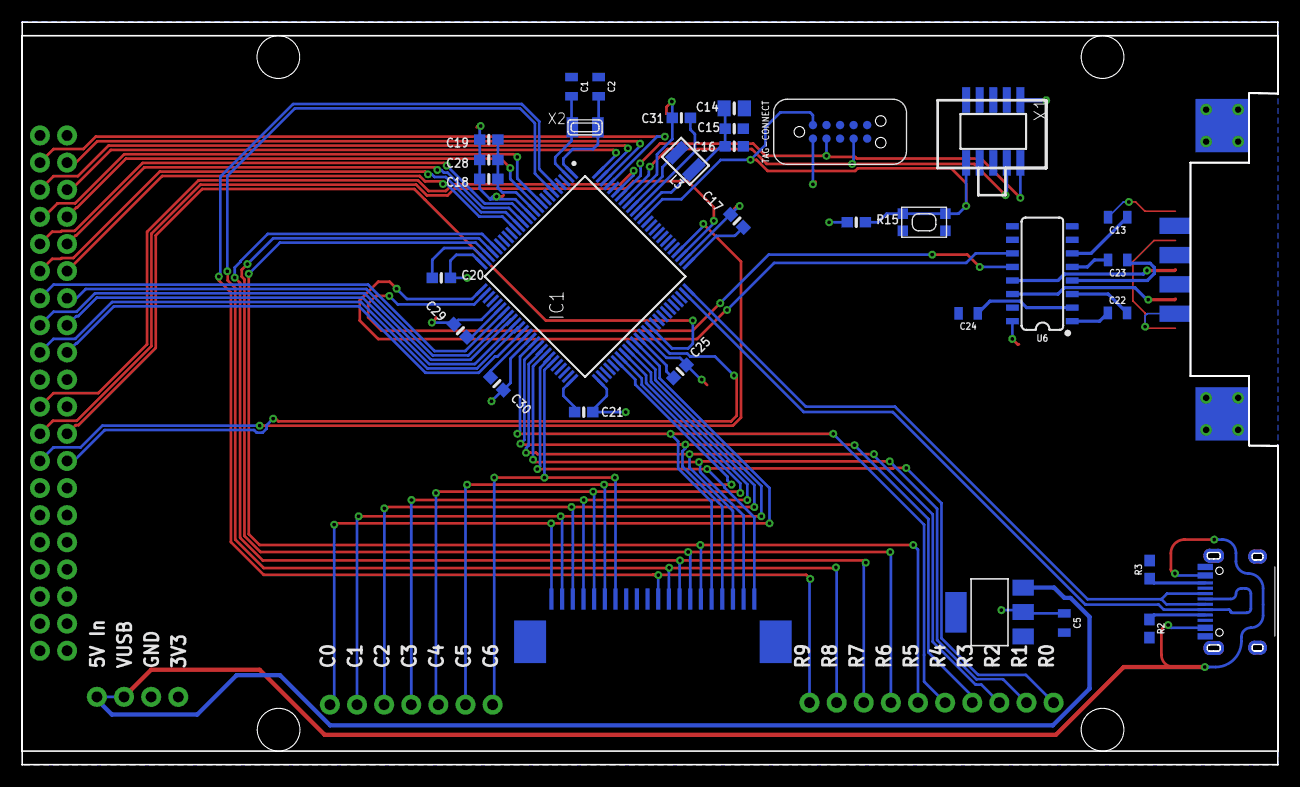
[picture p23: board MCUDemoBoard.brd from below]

Board: 2 copper layers, 117.6 x 69.5 mm, 38 parts (34 on the bottom side), 63 nets.

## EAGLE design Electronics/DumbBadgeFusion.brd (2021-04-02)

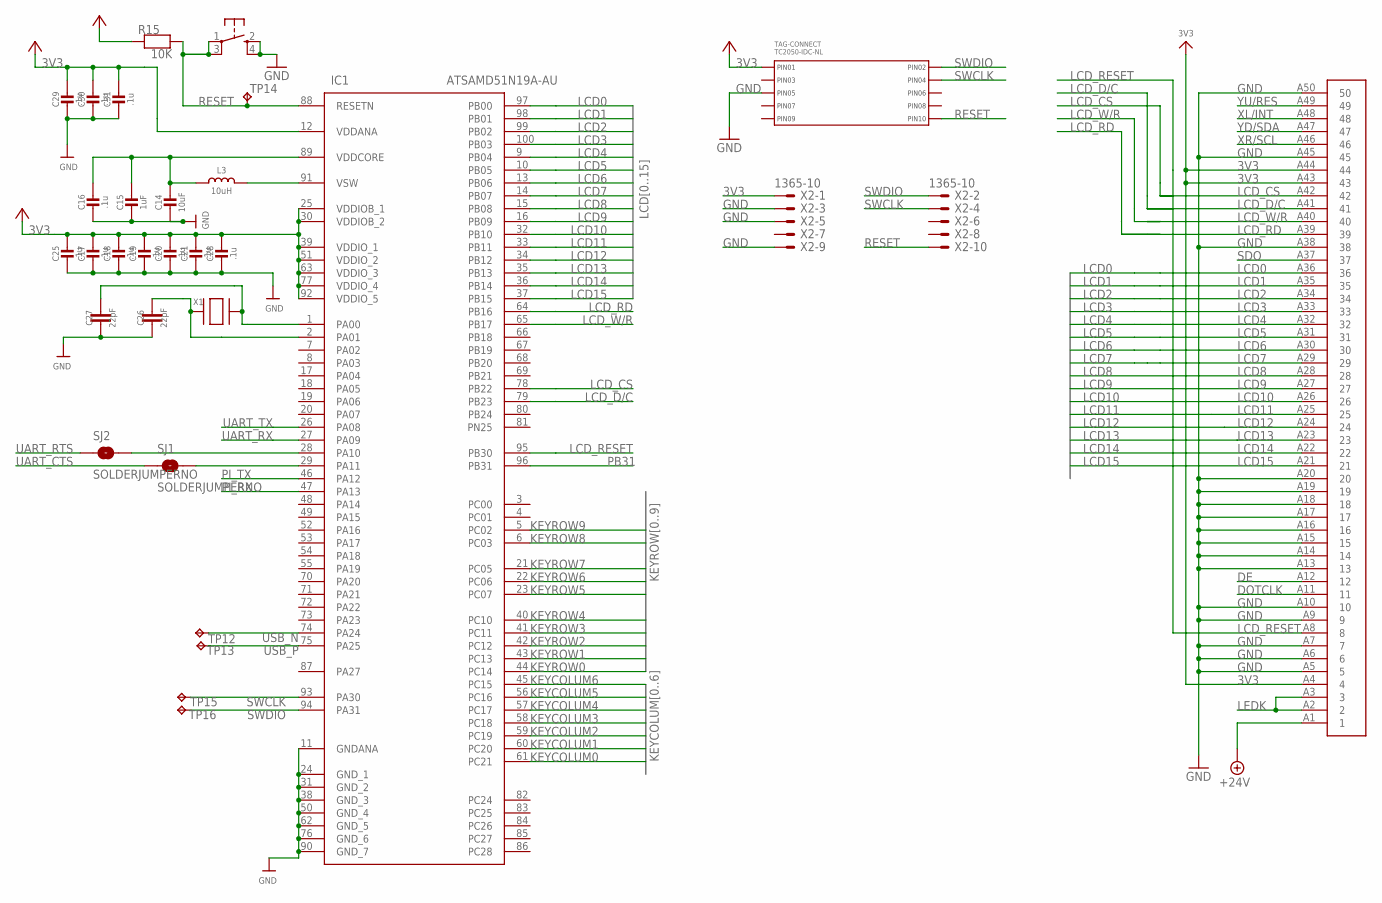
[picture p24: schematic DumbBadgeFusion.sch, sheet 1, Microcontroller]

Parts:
C14: 10uF; 0805-NO
C15: 1uF; 0603-NO
C16, C17, C18, C19, C20, C21, C25, C28, C29, C30, C31: .1u; 0603-NO
C26, C27: 22pF; 0805
FPC50CONN: 50PINFPC; 62684-501100ALF
IC1: ATSAMD51N19A-AU; QFP50P1600X1600X120-100N
L3: 10uH; INDUCTOR_1007
R15: 10K; 0603-NO
SJ1, SJ2: SOLDERJUMPERNO; SJ_2S-NO
SW1: SPST_TACT-KMR2; KMR2
TAG-CONNECT: TC2050-IDC-NL
TP12, TP13, TP14, TP15, TP16: TPB1,27; B1,27
X1: NX3215SA-32.768K-STD-MUA-8; XTAL3215
X2: 1365-10

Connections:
3V3: C17.2, C18.2, C19.2, C20.2, C21.2, C25.2, C28.2, C29.2, C30.2, C31.2, FPC50CONN.A4 (4), FPC50CONN.A43 (43), FPC50CONN.A44 (44), IC1.12 (VDDANA), IC1.25 (VDDIOB_1), IC1.30 (VDDIOB_2), IC1.39 (VDDIO_1), IC1.51 (VDDIO_2), IC1.63 (VDDIO_3), IC1.77 (VDDIO_4), IC1.92 (VDDIO_5), R15.1, TAG-CONNECT.P$1 (PIN1), X2.1; also elsewhere on the board
+24V: FPC50CONN.A1 (1); also elsewhere on the board
DE: FPC50CONN.A12 (12)
DOTCLK: FPC50CONN.A11 (11)
GND: C14.2, C15.2, C16.1, C17.1, C18.1, C19.1, C20.1, C21.1, C25.1, C26.1, C27.1, C28.1, C29.1, C30.1, C31.1, FPC50CONN.A5 (5), FPC50CONN.A6 (6), FPC50CONN.A7 (7), FPC50CONN.A9 (9), FPC50CONN.A10 (10), FPC50CONN.A13 (13), FPC50CONN.A14 (14), FPC50CONN.A15 (15), FPC50CONN.A16 (16), FPC50CONN.A17 (17), FPC50CONN.A18 (18), FPC50CONN.A19 (19), FPC50CONN.A20 (20), FPC50CONN.A38 (38), FPC50CONN.A45 (45), FPC50CONN.A50 (50), IC1.11 (GNDANA), IC1.24 (GND_1), IC1.31 (GND_2), IC1.38 (GND_3), IC1.50 (GND_4), IC1.62 (GND_5), IC1.76 (GND_6), IC1.90 (GND_7), SW1.2 (S), SW1.4 (S1), TAG-CONNECT.P$5 (PIN5), X2.3, X2.5, X2.9; also elsewhere on the board
KEYCOLUM0: IC1.61 (PC21); also elsewhere on the board
KEYCOLUM1: IC1.60 (PC20); also elsewhere on the board
KEYCOLUM2: IC1.59 (PC19); also elsewhere on the board
KEYCOLUM3: IC1.58 (PC18); also elsewhere on the board
KEYCOLUM4: IC1.57 (PC17); also elsewhere on the board
KEYCOLUM5: IC1.56 (PC16); also elsewhere on the board
KEYCOLUM6: IC1.45 (PC15); also elsewhere on the board
KEYROW0: IC1.44 (PC14); also elsewhere on the board
KEYROW1: IC1.43 (PC13); also elsewhere on the board
KEYROW2: IC1.42 (PC12); also elsewhere on the board
KEYROW3: IC1.41 (PC11); also elsewhere on the board
KEYROW4: IC1.40 (PC10); also elsewhere on the board
KEYROW5: IC1.23 (PC07); also elsewhere on the board
KEYROW6: IC1.22 (PC06); also elsewhere on the board
KEYROW7: IC1.21 (PC05); also elsewhere on the board
KEYROW8: IC1.6 (PC03); also elsewhere on the board
KEYROW9: IC1.5 (PC02); also elsewhere on the board
LCD0: FPC50CONN.A36 (36), IC1.97 (PB00)
LCD1: FPC50CONN.A35 (35), IC1.98 (PB01)
LCD2: FPC50CONN.A34 (34), IC1.99 (PB02)
LCD3: FPC50CONN.A33 (33), IC1.100 (PB03)
LCD4: FPC50CONN.A32 (32), IC1.9 (PB04)
LCD5: FPC50CONN.A31 (31), IC1.10 (PB05)
LCD6: FPC50CONN.A30 (30), IC1.13 (PB06)
LCD7: FPC50CONN.A29 (29), IC1.14 (PB07)
LCD8: FPC50CONN.A28 (28), IC1.15 (PB08)
LCD9: FPC50CONN.A27 (27), IC1.16 (PB09)
LCD10: FPC50CONN.A26 (26), IC1.32 (PB10)
LCD11: FPC50CONN.A25 (25), IC1.33 (PB11)
LCD12: FPC50CONN.A24 (24), IC1.34 (PB12)
LCD13: FPC50CONN.A23 (23), IC1.35 (PB13)
LCD14: FPC50CONN.A22 (22), IC1.36 (PB14)
LCD15: FPC50CONN.A21 (21), IC1.37 (PB15)
LCD_CS: FPC50CONN.A42 (42), IC1.78 (PB22)
LCD_D/C: FPC50CONN.A41 (41), IC1.79 (PB23)
LCD_RD: FPC50CONN.A39 (39), IC1.64 (PB16)
LCD_RESET: FPC50CONN.A8 (8), IC1.95 (PB30)
LCD_W/R: FPC50CONN.A40 (40), IC1.65 (PB17)
LEDK: FPC50CONN.A2 (2), FPC50CONN.A3 (3); also elsewhere on the board
unnamed: IC1.28 (PA10), SJ2.2
unnamed: C14.1, C15.1, C16.2, IC1.89 (VDDCORE), L3.P$1 (1)
unnamed: IC1.91 (VSW), L3.P$2 (2)
unnamed: IC1.29 (PA11), SJ1.2
unnamed: C27.2, IC1.1 (PA00), X1.P$1
unnamed: C26.2, IC1.2 (PA01), X1.P$2
PB31: IC1.96 (PB31); also elsewhere on the board
PI_RX: IC1.47 (PA13); also elsewhere on the board
PI_TX: IC1.46 (PA12); also elsewhere on the board
RESET: IC1.88 (RESETN), R15.2, SW1.1, SW1.3 (P1), TAG-CONNECT.P$10 (PIN10), TP14.TP, X2.10
SDO: FPC50CONN.A37 (37)
SWCLK: IC1.93 (PA30), TAG-CONNECT.P$4 (PIN4), TP15.TP, X2.4
SWDIO: IC1.94 (PA31), TAG-CONNECT.P$2 (PIN2), TP16.TP, X2.2
UART_CTS: SJ1.1; also elsewhere on the board
UART_RTS: SJ2.1; also elsewhere on the board
UART_RX: IC1.27 (PA09); also elsewhere on the board
UART_TX: IC1.26 (PA08); also elsewhere on the board
USB_N: IC1.74 (PA24), TP12.TP; also elsewhere on the board
USB_P: IC1.75 (PA25), TP13.TP; also elsewhere on the board
XL/INT: FPC50CONN.A48 (48)
XR/SCL: FPC50CONN.A46 (46)
YD/SDA: FPC50CONN.A47 (47)
YU/RES: FPC50CONN.A49 (49)

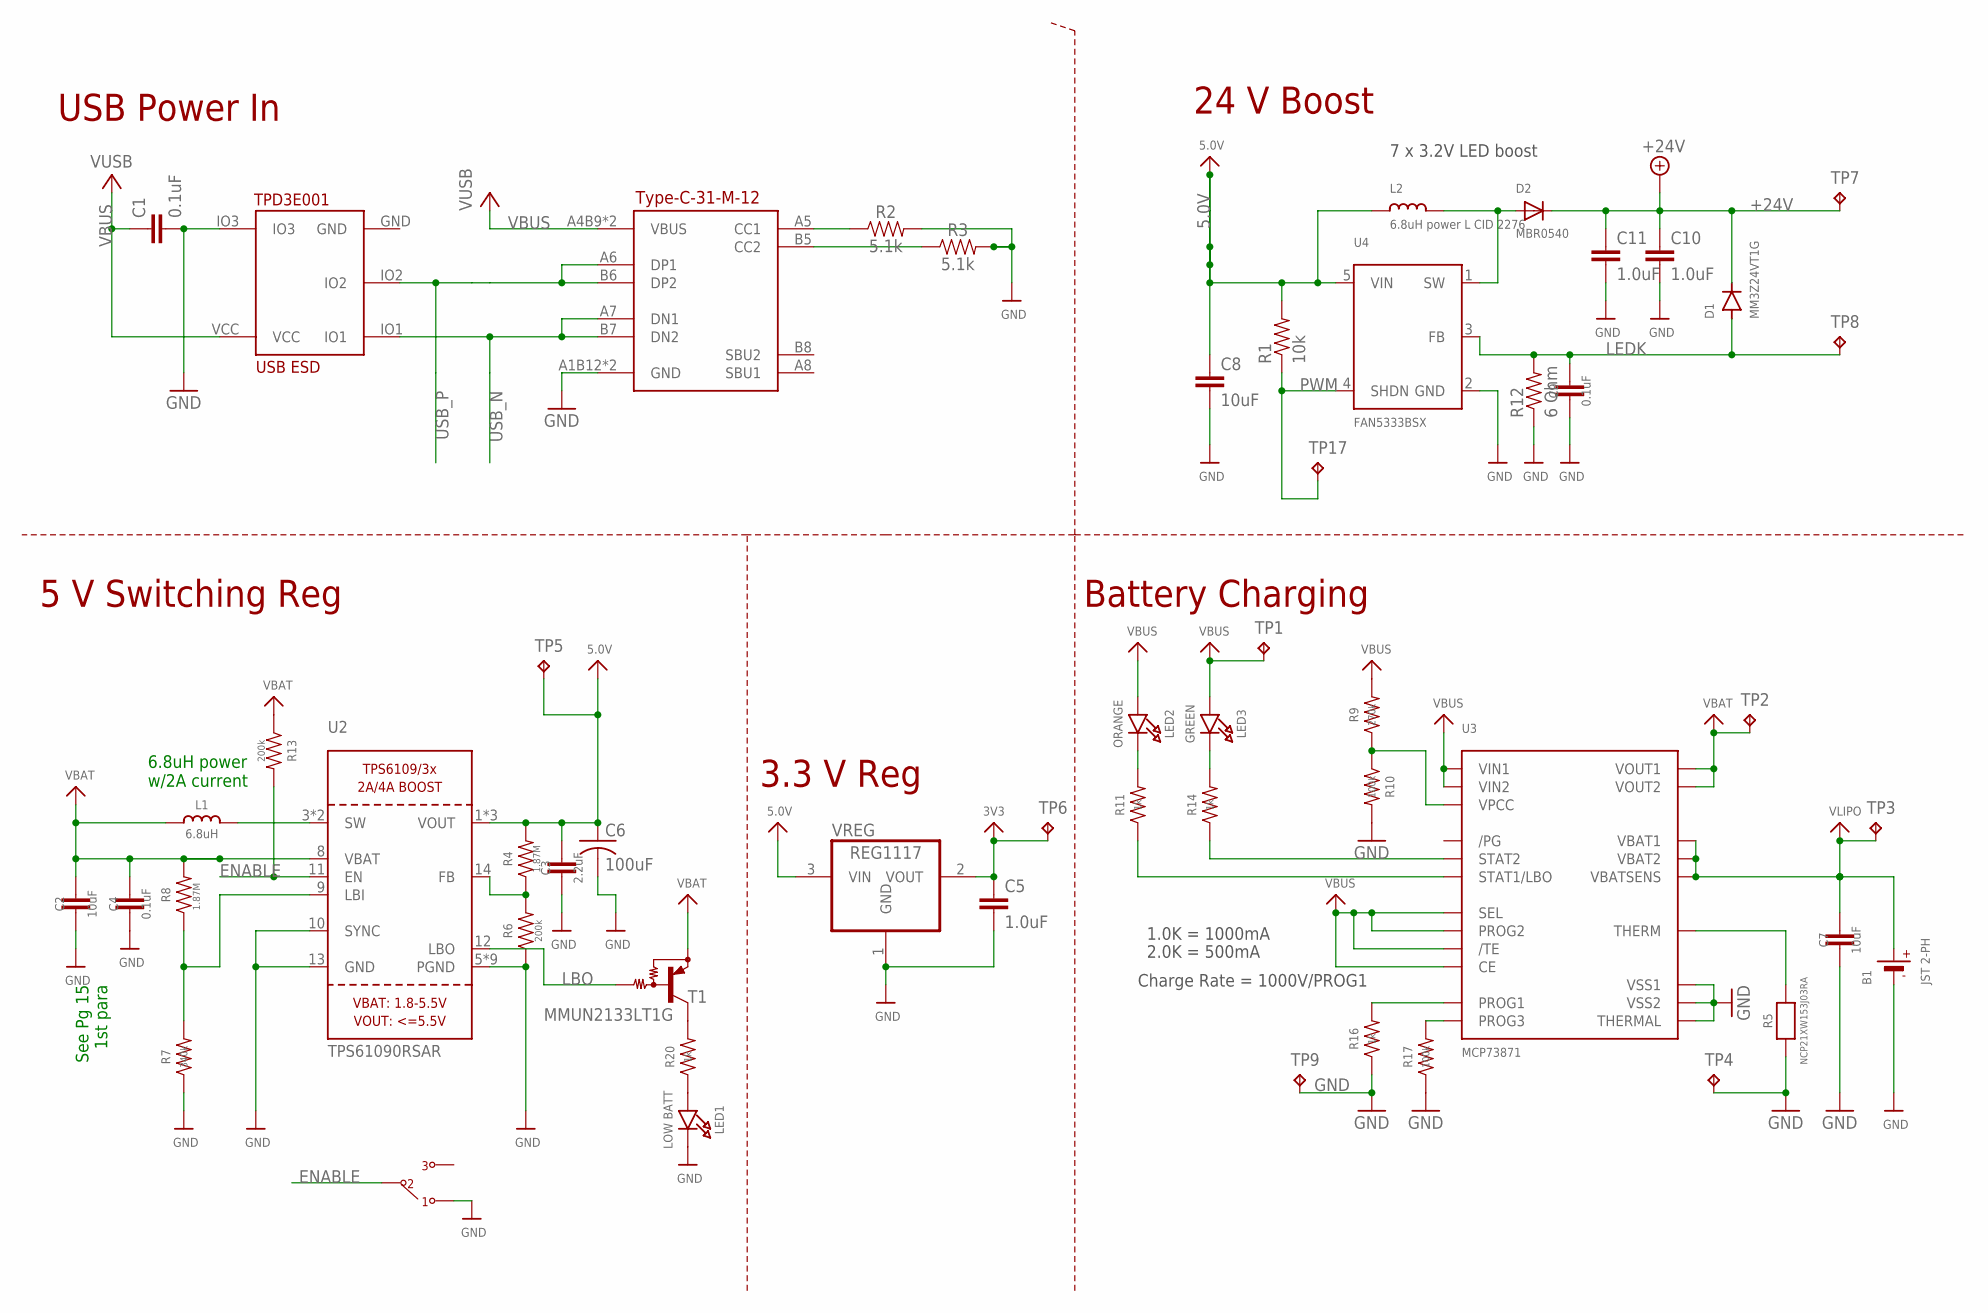
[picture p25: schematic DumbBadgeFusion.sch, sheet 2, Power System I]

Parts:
B1: JST 2-PH; JSTPH2
C1, C4, C9: 0.1uF; 0805
C2, C7, C8: 10uF; 0805
C3: 2.2uF; 0805
C5, C10, C11: 1.0uF; 0805
C6: 100uF; C1210
D1: MM3Z24VT1G; SOD323-W
D2: MBR0540; SOD-123
L1: 6.8uH; INDUCTOR_5X5MM_TDK_VLC5045
L2: 6.8uH power L CID 2276; INDUCTOR_5X5MM_NR5040_NOTHERMALS
LED1: LOW BATT; CHIPLED_0805_NOOUTLINE
LED2: ORANGE; CHIPLED_0805_NOOUTLINE
LED3: GREEN; CHIPLED_0805_NOOUTLINE
R1: 10k; 0603
R2, R3: 5.1k; 0603
R4, R8: 1.87M; 0603
R5: NCP21XW153J03RA; 0805-NO
R6, R13: 200k; 0603
R7: 340k; 0603
R9: 270k; 0603
R10, R17: 100k; 0603
R11, R14, R16, R20: 1k; 0603
R12: 6 Ohm; 0603
T1: MMUN2133LT1G; SC59-BEC
TP1, TP2, TP3, TP4, TP5, TP6, TP7, TP8, TP9, TP17: TPB1,27; B1,27
U2: TPS61090RSAR; PVQFN-16
U3: MCP73871; QFN20_4MM
U4: FAN5333BSX; SOT23-5@1
U5: TPD3E001SOT5; SOT(5)
U$5: OS102011MA1QN1
USB: TYPE-C-31-M-12
VREG: REG1117; SOT223

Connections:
3V3: C5.1, TP6.TP, VREG.2 (VOUT); also elsewhere on the board
5.0V: C3.1, C6.1, C8.1, L2.P$1 (1), R1.2, R4.2, TP5.TP, U2.1 (VOUT), U2.15 (VOUT), U2.16 (VOUT), U4.5 (VIN), VREG.3 (VIN); also elsewhere on the board
+24V: C10.1, C11.1, D1.C, D2.C, TP7.TP; also elsewhere on the board
ENABLE: R13.2, U2.11 (EN), U$5.P$2
GND: B1.1 (-), C1.2, C2.2, C3.2, C4.2, C5.2, C6.2, C7.2, C8.2, C9.2, C10.2, C11.2, LED1.C, R2.2, R3.2, R5.1, R6.1, R7.1, R10.2, R12.1, R16.1, R17.1, TP4.TP, TP9.TP, U2.5 (PGND), U2.6 (PGND), U2.7 (PGND), U2.10 (SYNC), U2.13 (GND), U2.P$18 (PGND), U2.P$19 (PGND), U2.P$20 (PGND), U2.P$21 (PGND), U2.P$22 (PGND), U2.THERMAL (PGND), U3.P$10 (VSS1), U3.P$11 (VSS2), U3.P$21 (THERMAL), U4.2 (GND), U5.IO3, U$5.P$1, USB.A1B12 (GND), USB.B1A12 (GND), VREG.1 (GND); also elsewhere on the board
LBO: T1.B, U2.12 (LBO)
LEDK: C9.1, D1.A, R12.2, TP8.TP, U4.3 (FB); also elsewhere on the board
unnamed: L1.P$2 (2), U2.3 (SW), U2.4 (SW)
unnamed: R7.2, R8.1, U2.9 (LBI)
unnamed: LED1.A, R20.1
unnamed: R4.1, R6.2, U2.14 (FB)
unnamed: R20.2, T1.C
unnamed: R9.1, R10.1, U3.P$2 (VPCC)
unnamed: R14.1, U3.P$7 (STAT2)
unnamed: R11.1, U3.P$8 (STAT1/LBO)
unnamed: R5.2, U3.P$5 (THERM)
unnamed: R16.2, U3.P$13 (PROG1)
unnamed: LED3.C, R14.2
unnamed: LED2.C, R11.2
unnamed: R17.2, U3.P$12 (PROG3)
unnamed: D2.A, L2.P$2 (2), U4.1 (SW)
unnamed: R2.1, USB.A5 (CC1)
unnamed: R3.1, USB.B5 (CC2)
PWM: R1.1, TP17.TP, U4.4 (SHDN)
USB_N: U5.IO1, USB.A7 (DN1), USB.B7 (DN2); also elsewhere on the board
USB_P: U5.IO2, USB.A6 (DP1), USB.B6 (DP2); also elsewhere on the board
VBAT: C2.1, C4.1, L1.P$1 (1), R8.2, R13.1, T1.E, TP2.TP, U2.8 (VBAT), U3.P$1 (VOUT1), U3.P$20 (VOUT2)
VBUS: C1.1, LED2.A, LED3.A, R9.2, TP1.TP, U3.P$3 (SEL), U3.P$4 (PROG2), U3.P$9 (/TE), U3.P$17 (CE), U3.P$18 (VIN1), U3.P$19 (VIN2), U5.VCC, USB.A4B9 (VBUS), USB.B4A9 (VBUS)
VLIPO: B1.2 (+), C7.1, TP3.TP, U3.P$14 (VBAT1), U3.P$15 (VBAT2), U3.P$16 (VBATSENS)

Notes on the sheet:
Type-C-31-M-12
USB Power In
See Pg 15 1st para
6.8uH power w/2A current
Charge Rate = 1000V/PROG1
1.0K = 1000mA
2.0K = 500mA
3.3 V Reg
Battery Charging
5 V Switching Reg
7 x 3.2V LED boost
24 V Boost

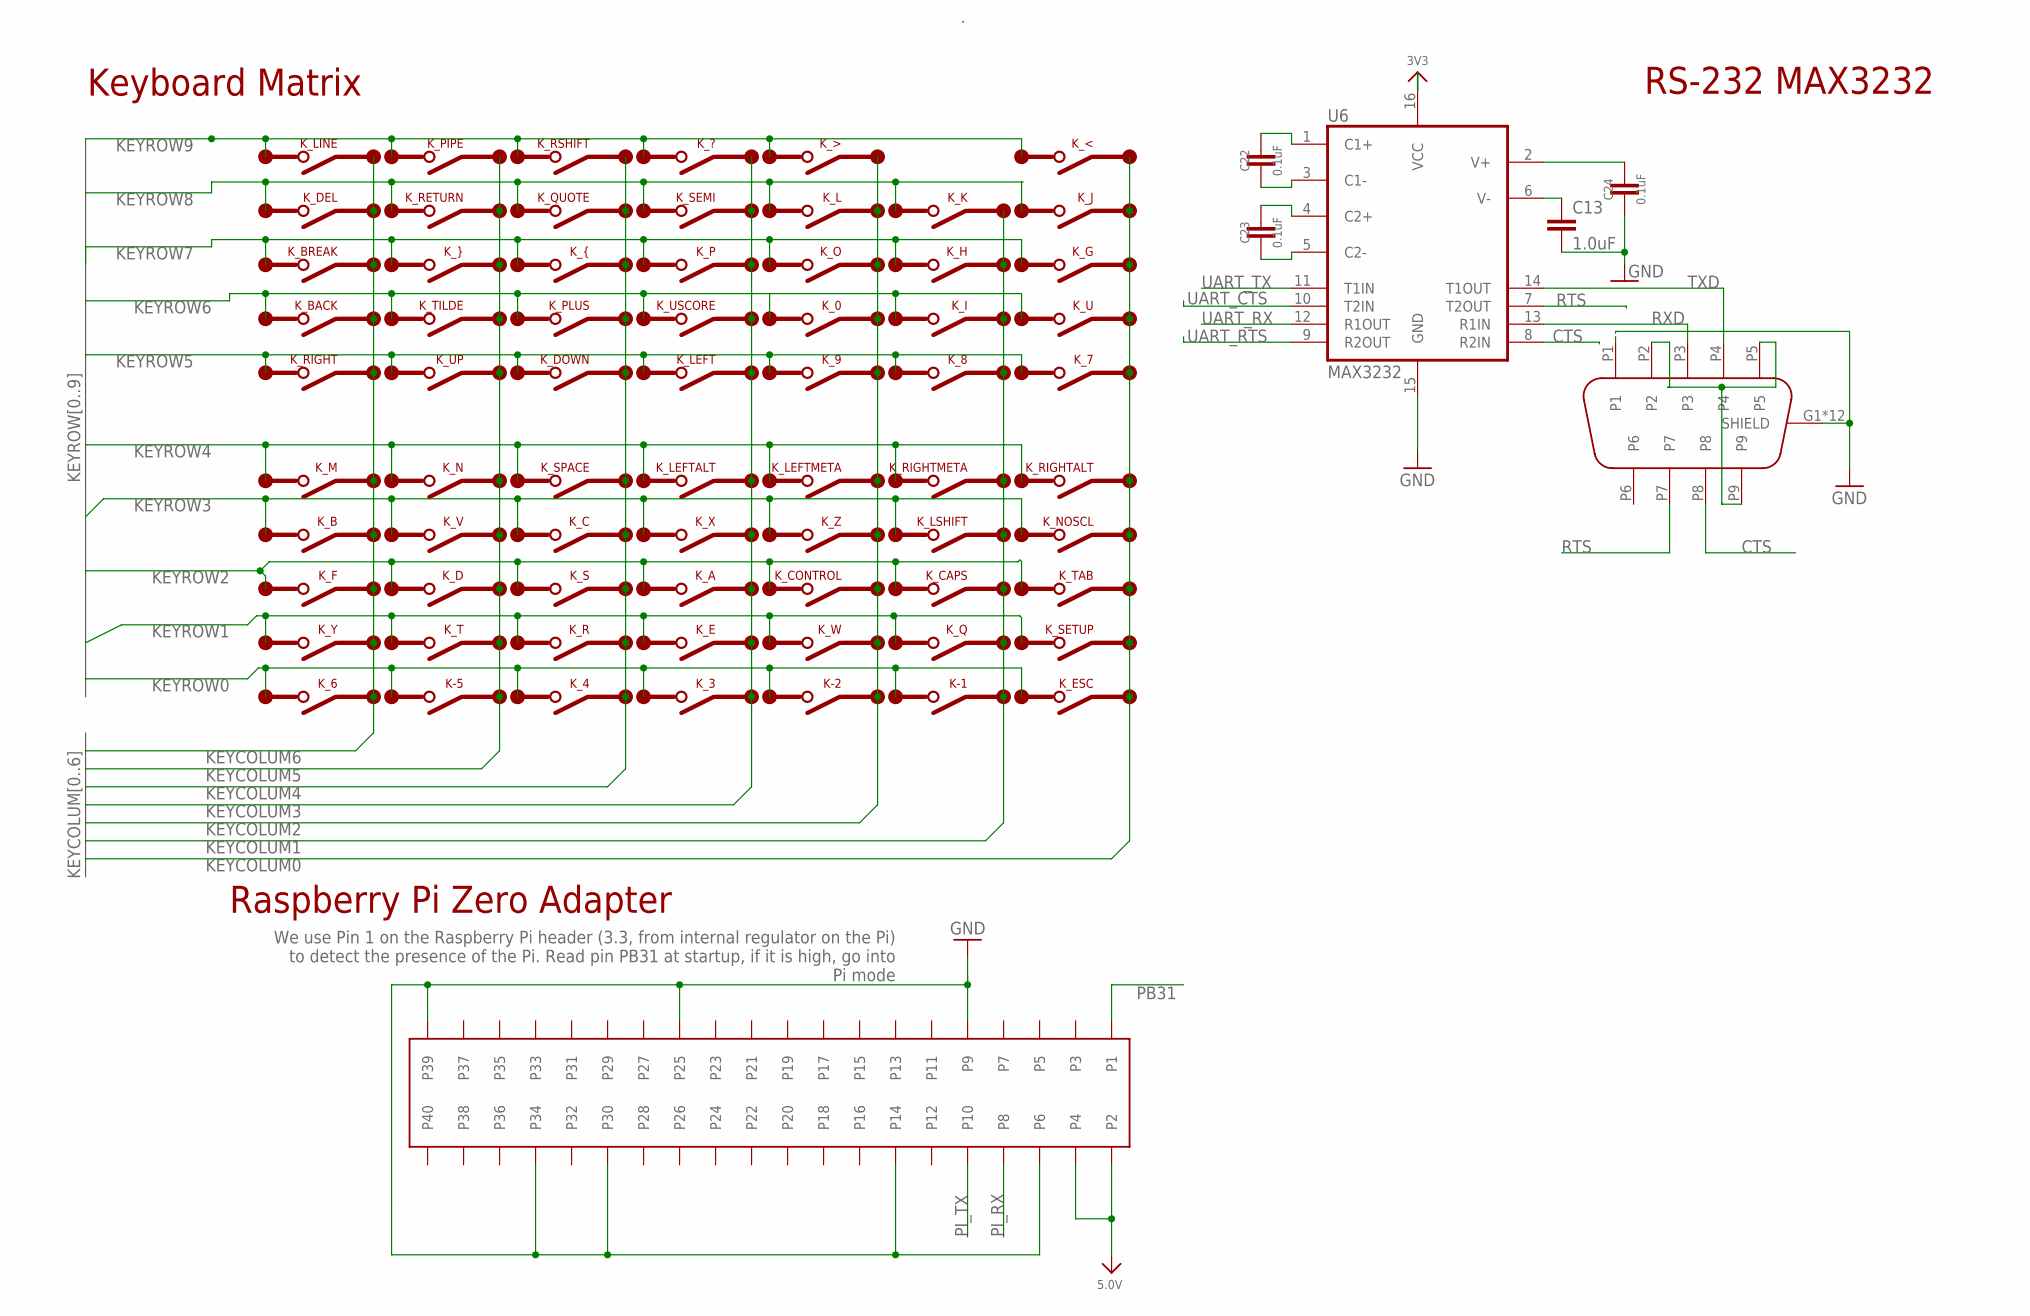
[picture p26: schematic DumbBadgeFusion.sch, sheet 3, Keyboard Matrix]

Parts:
C13: 1.0uF; 0805
C22, C23, C24: 0.1uF; 0805
DE9FEMALE: EDGEMOUNTDE9; DE09S065TLF
K-1, K-2, K-5: 1U_PAD; SILICONE_SWITCH
K_0, K_3, K_4, K_6, K_7, K_8, K_9: 1U_PAD; SILICONE_SWITCH
K_<: 1U_PAD; SILICONE_SWITCH
K_>: 1U_PAD; SILICONE_SWITCH
K_?: 1U_PAD; SILICONE_SWITCH
K_A: 1U_PAD; SILICONE_SWITCH
K_B: 1U_PAD; SILICONE_SWITCH
K_BACK: 1U_PAD; SILICONE_SWITCH
K_BREAK: 1U_PAD; SILICONE_SWITCH
K_C: 1U_PAD; SILICONE_SWITCH
K_CAPS: 1U_PAD; SILICONE_SWITCH
K_CONTROL: 2U_PAD; SILICONE_SWITCH_2U
K_D: 1U_PAD; SILICONE_SWITCH
K_DEL: 1U_PAD; SILICONE_SWITCH
K_DOWN: 1U_PAD; SILICONE_SWITCH
K_E: 1U_PAD; SILICONE_SWITCH
K_ESC: 1U_PAD; SILICONE_SWITCH
K_F: 1U_PAD; SILICONE_SWITCH
K_G: 1U_PAD; SILICONE_SWITCH
K_H: 1U_PAD; SILICONE_SWITCH
K_I: 1U_PAD; SILICONE_SWITCH
K_J: 1U_PAD; SILICONE_SWITCH
K_K: 1U_PAD; SILICONE_SWITCH
K_L: 1U_PAD; SILICONE_SWITCH
K_LEFT: 1U_PAD; SILICONE_SWITCH
K_LEFTALT: 1U_PAD; SILICONE_SWITCH
K_LEFTMETA: 1U_PAD; SILICONE_SWITCH
K_LINE: 1U_PAD; SILICONE_SWITCH
K_LSHIFT: 2U_PAD; SILICONE_SWITCH_2U
K_M: 1U_PAD; SILICONE_SWITCH
K_N: 1U_PAD; SILICONE_SWITCH
K_NOSCL: 1U_PAD; SILICONE_SWITCH
K_O: 1U_PAD; SILICONE_SWITCH
K_P: 1U_PAD; SILICONE_SWITCH
K_PIPE: 1U_PAD; SILICONE_SWITCH
K_PLUS: 1U_PAD; SILICONE_SWITCH
K_Q: 1U_PAD; SILICONE_SWITCH
K_QUOTE: 1U_PAD; SILICONE_SWITCH
K_R: 1U_PAD; SILICONE_SWITCH
K_RETURN: RETURN_PAD; SILICONE_RETURN
K_RIGHT: 1U_PAD; SILICONE_SWITCH
K_RIGHTALT: 1U_PAD; SILICONE_SWITCH
K_RIGHTMETA: 1U_PAD; SILICONE_SWITCH
K_RSHIFT: 2U_PAD; SILICONE_SWITCH_2U
K_S: 1U_PAD; SILICONE_SWITCH
K_SEMI: 1U_PAD; SILICONE_SWITCH
K_SETUP: 2U_PAD; SILICONE_SWITCH_2U
K_SPACE: SPACE_PAD; SILICONE_SPACE
K_T: 1U_PAD; SILICONE_SWITCH
K_TAB: 1U_PAD; SILICONE_SWITCH
K_TILDE: 1U_PAD; SILICONE_SWITCH
K_U: 1U_PAD; SILICONE_SWITCH
K_UP: 1U_PAD; SILICONE_SWITCH
K_USCORE: 1U_PAD; SILICONE_SWITCH
K_V: 1U_PAD; SILICONE_SWITCH
K_W: 1U_PAD; SILICONE_SWITCH
K_X: 1U_PAD; SILICONE_SWITCH
K_Y: 1U_PAD; SILICONE_SWITCH
K_Z: 1U_PAD; SILICONE_SWITCH
K_{: 1U_PAD; SILICONE_SWITCH
K_}: 1U_PAD; SILICONE_SWITCH
U6: MAX3232; SO16
U$30: SAMTEC_PI_REVERSE; HLE-120-02-G-DV-BE-A--REVERSEMOUNT

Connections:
3V3: U6.16 (VCC); also elsewhere on the board
5.0V: U$30.P2, U$30.P4; also elsewhere on the board
CTS: DE9FEMALE.P8, U6.8 (R2IN)
GND: C13.2, C24.2, DE9FEMALE.G1 (SHIELD), DE9FEMALE.G2 (SHIELD), DE9FEMALE.G3 (SHIELD), DE9FEMALE.G4 (SHIELD), DE9FEMALE.G5 (SHIELD), DE9FEMALE.G6 (SHIELD), DE9FEMALE.G7 (SHIELD), DE9FEMALE.G8 (SHIELD), DE9FEMALE.G9 (SHIELD), DE9FEMALE.G10 (SHIELD), DE9FEMALE.G11 (SHIELD), DE9FEMALE.G12 (SHIELD), DE9FEMALE.P1, U6.15 (GND), U$30.P6, U$30.P9, U$30.P14, U$30.P25, U$30.P30, U$30.P34, U$30.P39; also elsewhere on the board
KEYCOLUM0: K_7.P$2, K_<.P$2, K_ESC.P$2, K_G.P$2, K_J.P$2, K_NOSCL.P$2, K_RIGHTALT.P$2, K_SETUP.P$2, K_TAB.P$2, K_U.P$2; also elsewhere on the board
KEYCOLUM1: K-1.P$2, K_8.P$2, K_CAPS.P$2, K_H.P$2, K_I.P$2, K_K.P$2, K_LSHIFT.P$2, K_Q.P$2, K_RIGHTMETA.P$2; also elsewhere on the board
KEYCOLUM2: K-2.P$2, K_0.P$2, K_9.P$2, K_>.P$2, K_CONTROL.P$2, K_L.P$2, K_LEFTMETA.P$2, K_O.P$2, K_W.P$2, K_Z.P$2; also elsewhere on the board
KEYCOLUM3: K_3.P$2, K_?.P$2, K_A.P$2, K_E.P$2, K_LEFT.P$2, K_LEFTALT.P$2, K_P.P$2, K_SEMI.P$2, K_USCORE.P$2, K_X.P$2; also elsewhere on the board
KEYCOLUM4: K_4.P$2, K_C.P$2, K_DOWN.P$2, K_PLUS.P$2, K_QUOTE.P$2, K_R.P$2, K_RSHIFT.P$2, K_S.P$2, K_SPACE.P$2, K_{.P$2; also elsewhere on the board
KEYCOLUM5: K-5.P$2, K_D.P$2, K_N.P$2, K_PIPE.P$2, K_RETURN.P$2, K_T.P$2, K_TILDE.P$2, K_UP.P$2, K_V.P$2, K_}.P$2; also elsewhere on the board
KEYCOLUM6: K_6.P$2, K_B.P$2, K_BACK.P$2, K_BREAK.P$2, K_DEL.P$2, K_F.P$2, K_LINE.P$2, K_M.P$2, K_RIGHT.P$2, K_Y.P$2; also elsewhere on the board
KEYROW0: K-1.P$1, K-2.P$1, K-5.P$1, K_3.P$1, K_4.P$1, K_6.P$1, K_ESC.P$1; also elsewhere on the board
KEYROW1: K_E.P$1, K_Q.P$1, K_R.P$1, K_SETUP.P$1, K_T.P$1, K_W.P$1, K_Y.P$1; also elsewhere on the board
KEYROW2: K_A.P$1, K_CAPS.P$1, K_CONTROL.P$1, K_D.P$1, K_F.P$1, K_S.P$1, K_TAB.P$1; also elsewhere on the board
KEYROW3: K_B.P$1, K_C.P$1, K_LSHIFT.P$1, K_NOSCL.P$1, K_V.P$1, K_X.P$1, K_Z.P$1; also elsewhere on the board
KEYROW4: K_LEFTALT.P$1, K_LEFTMETA.P$1, K_M.P$1, K_N.P$1, K_RIGHTALT.P$1, K_RIGHTMETA.P$1, K_SPACE.P$1; also elsewhere on the board
KEYROW5: K_7.P$1, K_8.P$1, K_9.P$1, K_DOWN.P$1, K_LEFT.P$1, K_RIGHT.P$1, K_UP.P$1; also elsewhere on the board
KEYROW6: K_0.P$1, K_BACK.P$1, K_I.P$1, K_PLUS.P$1, K_TILDE.P$1, K_U.P$1, K_USCORE.P$1; also elsewhere on the board
KEYROW7: K_BREAK.P$1, K_G.P$1, K_H.P$1, K_O.P$1, K_P.P$1, K_{.P$1, K_}.P$1; also elsewhere on the board
KEYROW8: K_DEL.P$1, K_J.P$1, K_K.P$1, K_L.P$1, K_QUOTE.P$1, K_RETURN.P$1, K_SEMI.P$1; also elsewhere on the board
KEYROW9: K_<.P$1, K_>.P$1, K_?.P$1, K_LINE.P$1, K_PIPE.P$1, K_RSHIFT.P$1; also elsewhere on the board
unnamed: C24.1, U6.2 (V+)
unnamed: C22.2, U6.3 (C1-)
unnamed: C22.1, U6.1 (C1+)
unnamed: C23.1, U6.4 (C2+)
unnamed: C23.2, U6.5 (C2-)
unnamed: C13.1, U6.6 (V-)
unnamed: DE9FEMALE.P2, DE9FEMALE.P5, DE9FEMALE.P9
PB31: U$30.P1; also elsewhere on the board
PI_RX: U$30.P8; also elsewhere on the board
PI_TX: U$30.P10; also elsewhere on the board
RTS: DE9FEMALE.P7, U6.7 (T2OUT)
RXD: DE9FEMALE.P3, U6.13 (R1IN)
TXD: DE9FEMALE.P4, U6.14 (T1OUT)
UART_CTS: U6.10 (T2IN); also elsewhere on the board
UART_RTS: U6.9 (R2OUT); also elsewhere on the board
UART_RX: U6.12 (R1OUT); also elsewhere on the board
UART_TX: U6.11 (T1IN); also elsewhere on the board

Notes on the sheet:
Keyboard Matrix
RS-232 MAX3232
Raspberry Pi Zero Adapter
We use Pin 1 on the Raspberry Pi header (3.3, from internal regulator on the Pi) to detect the presence of the Pi. Read pin PB31 at startup, if it is high, go into Pi mode

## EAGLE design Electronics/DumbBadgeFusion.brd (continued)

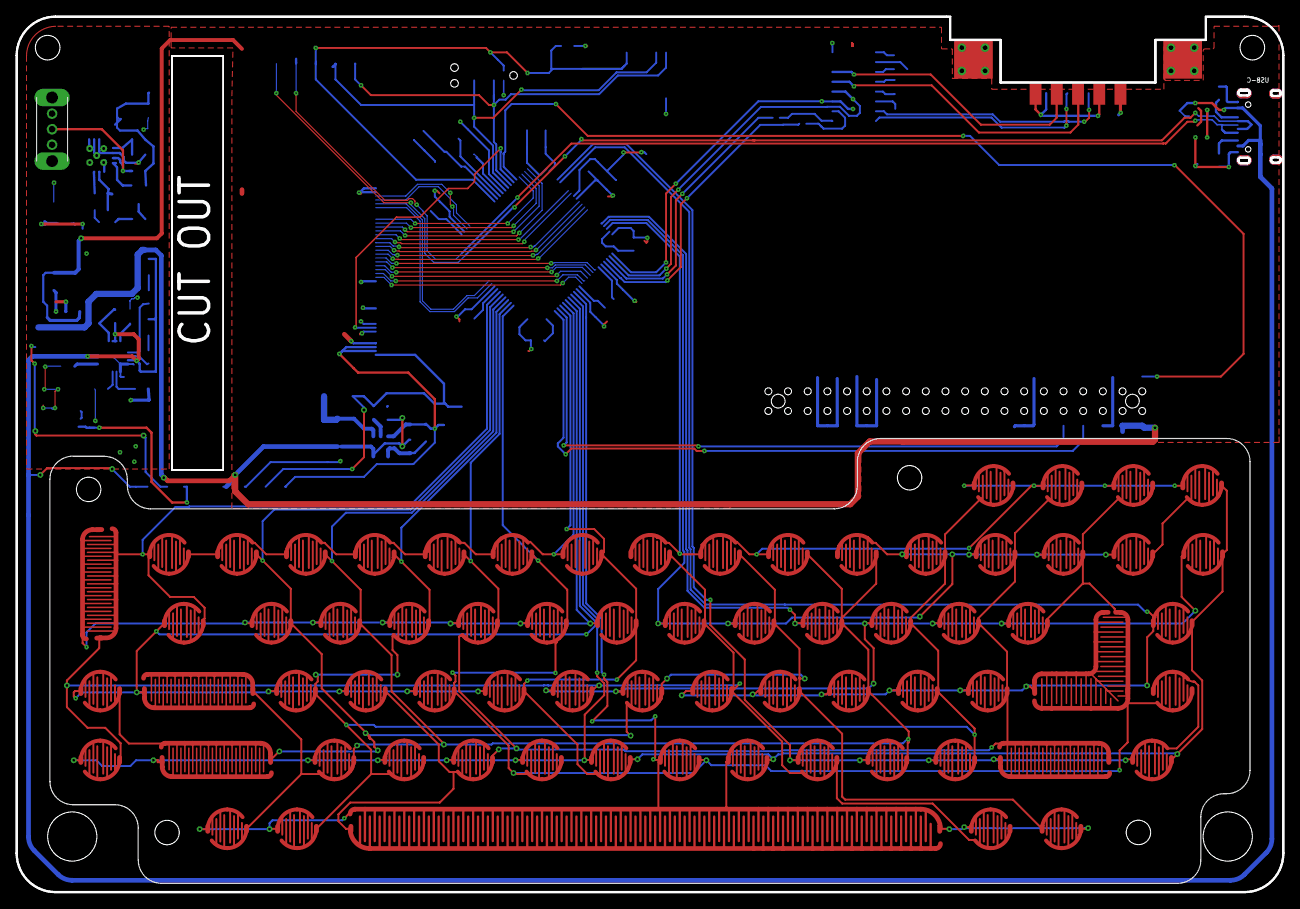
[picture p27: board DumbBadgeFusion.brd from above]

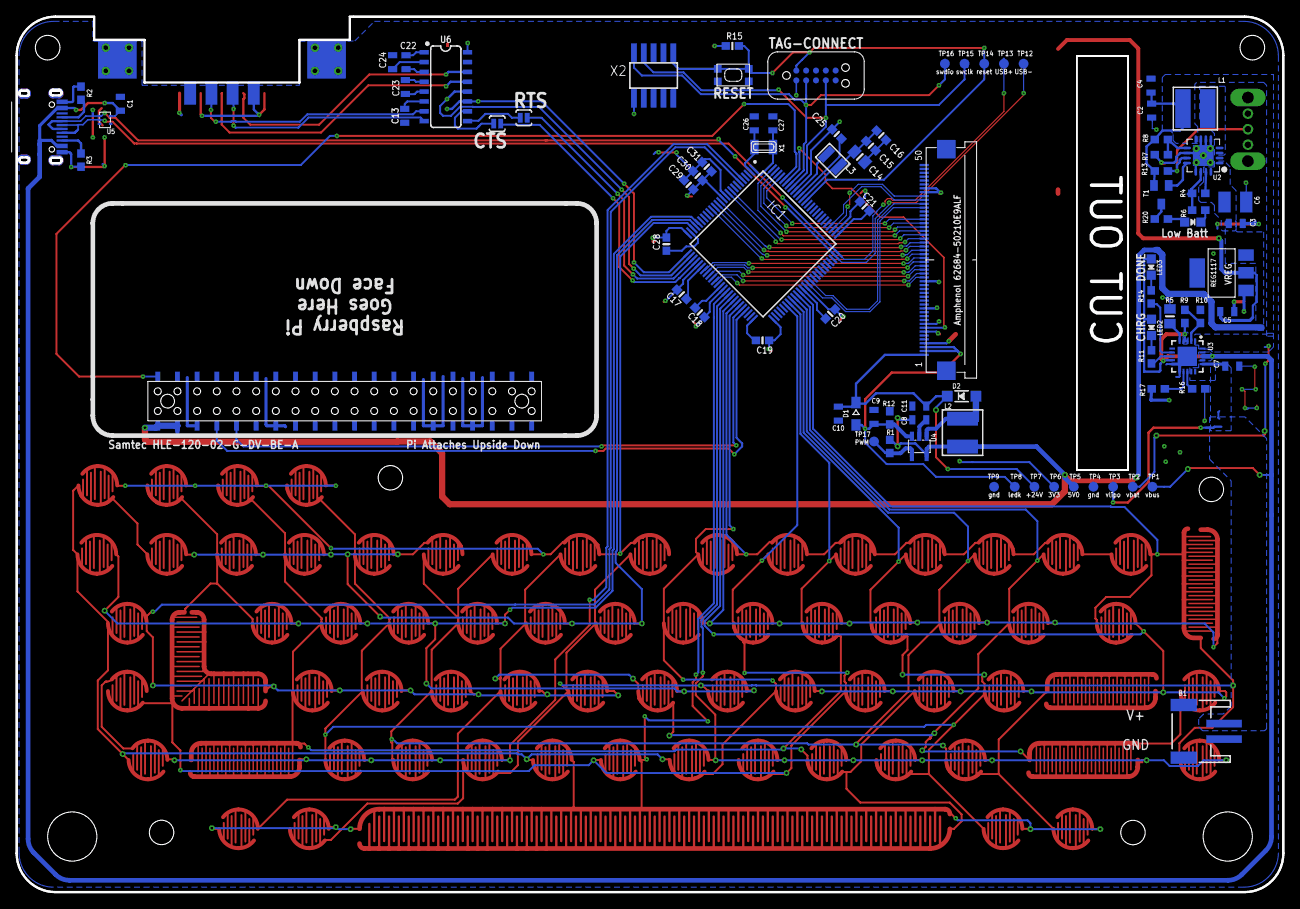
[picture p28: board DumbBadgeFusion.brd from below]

Board: 2 copper layers, 163.5 x 113.0 mm, 160 parts (89 on the bottom side), 94 nets.

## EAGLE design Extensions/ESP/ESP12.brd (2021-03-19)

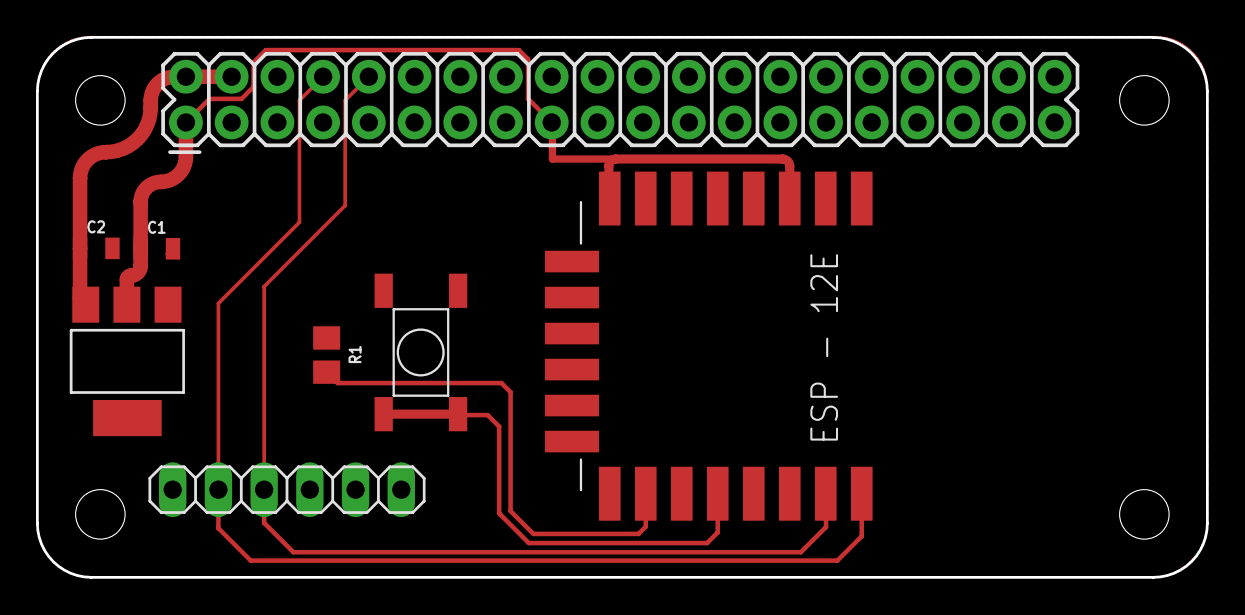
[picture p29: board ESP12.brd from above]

Board: 2 copper layers, 65.0 x 30.0 mm, 8 parts (0 on the bottom side), 7 nets.

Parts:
C1, C2: 10uF; 0805
FLASH: MOMENTARYSW; SWITCHMOMENTARY
IC1: REG1117; SOT223
J1: RASPBERRYPI-40-PIN-GPIO_PTH_NO_SHROUD; 2X20
JP2: 1X06
R1: 10k; R0805
U3: ESP12E-SMD

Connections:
5V: C2.1, IC1.3, J1.2, J1.4
FTDI_RX: J1.8, JP2.5, U3.TXD0
FTDI_TX: J1.10, JP2.4, U3.RXD0
GND: C1.2, C2.2, FLASH.R1, FLASH.R2, IC1.1, J1.6, J1.9, J1.14, J1.20, J1.25, J1.30, J1.34, J1.39, JP2.1, R1.1, U3.GND
unnamed: R1.2, U3.GPIO15
unnamed: FLASH.L1, FLASH.L2, U3.GPIO0
VCC: C1.1, IC1.2, J1.1, J1.17, U3.CH_PD, U3.VCC

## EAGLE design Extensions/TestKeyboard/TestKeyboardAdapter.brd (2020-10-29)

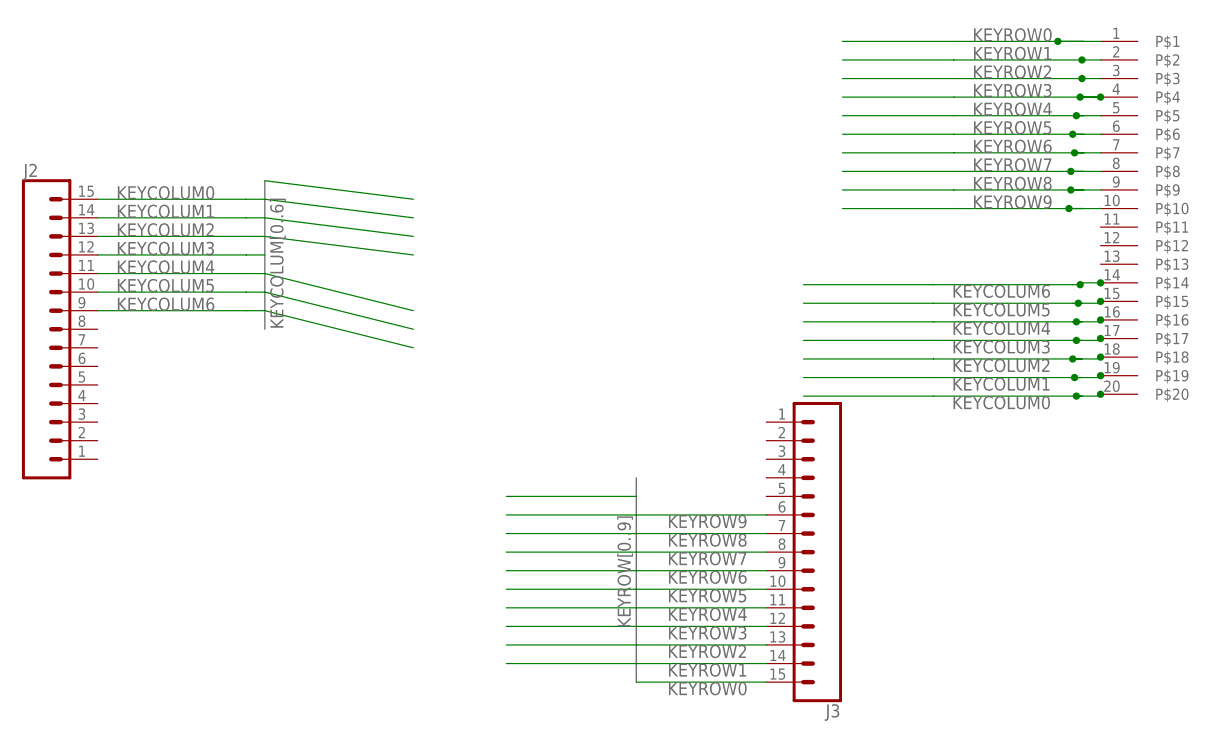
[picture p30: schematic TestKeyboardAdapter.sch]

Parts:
J2, J3: CONN_15; 1X15
U$1: FC1-20-L2-T-WT20PIN; FC1-20-L2-T-WT

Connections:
KEYCOLUM0: J2.15, U$1.20
KEYCOLUM1: J2.14, U$1.19
KEYCOLUM2: J2.13, U$1.18
KEYCOLUM3: J2.12, U$1.17
KEYCOLUM4: J2.11, U$1.16
KEYCOLUM5: J2.10, U$1.15
KEYCOLUM6: J2.9, U$1.14
KEYROW0: J3.15, U$1.1
KEYROW1: J3.14, U$1.2
KEYROW2: J3.13, U$1.3
KEYROW3: J3.12, U$1.4
KEYROW4: J3.11, U$1.5
KEYROW5: J3.10, U$1.6
KEYROW6: J3.9, U$1.7
KEYROW7: J3.8, U$1.8
KEYROW8: J3.7, U$1.9
KEYROW9: J3.6, U$1.10

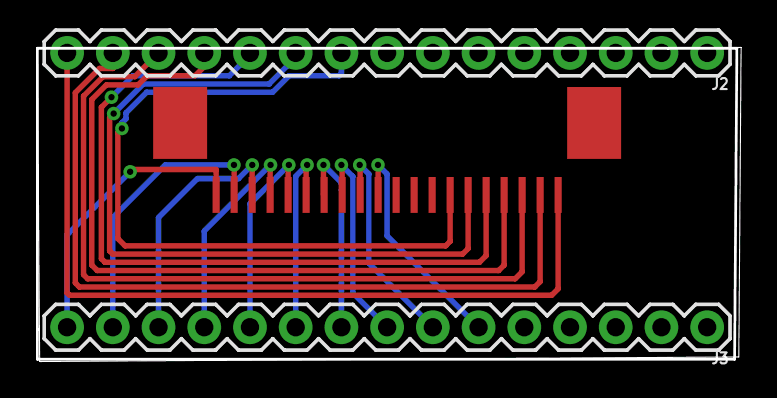
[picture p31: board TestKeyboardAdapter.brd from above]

Board: 2 copper layers, 39.1 x 17.4 mm, 3 parts (0 on the bottom side), 17 nets.

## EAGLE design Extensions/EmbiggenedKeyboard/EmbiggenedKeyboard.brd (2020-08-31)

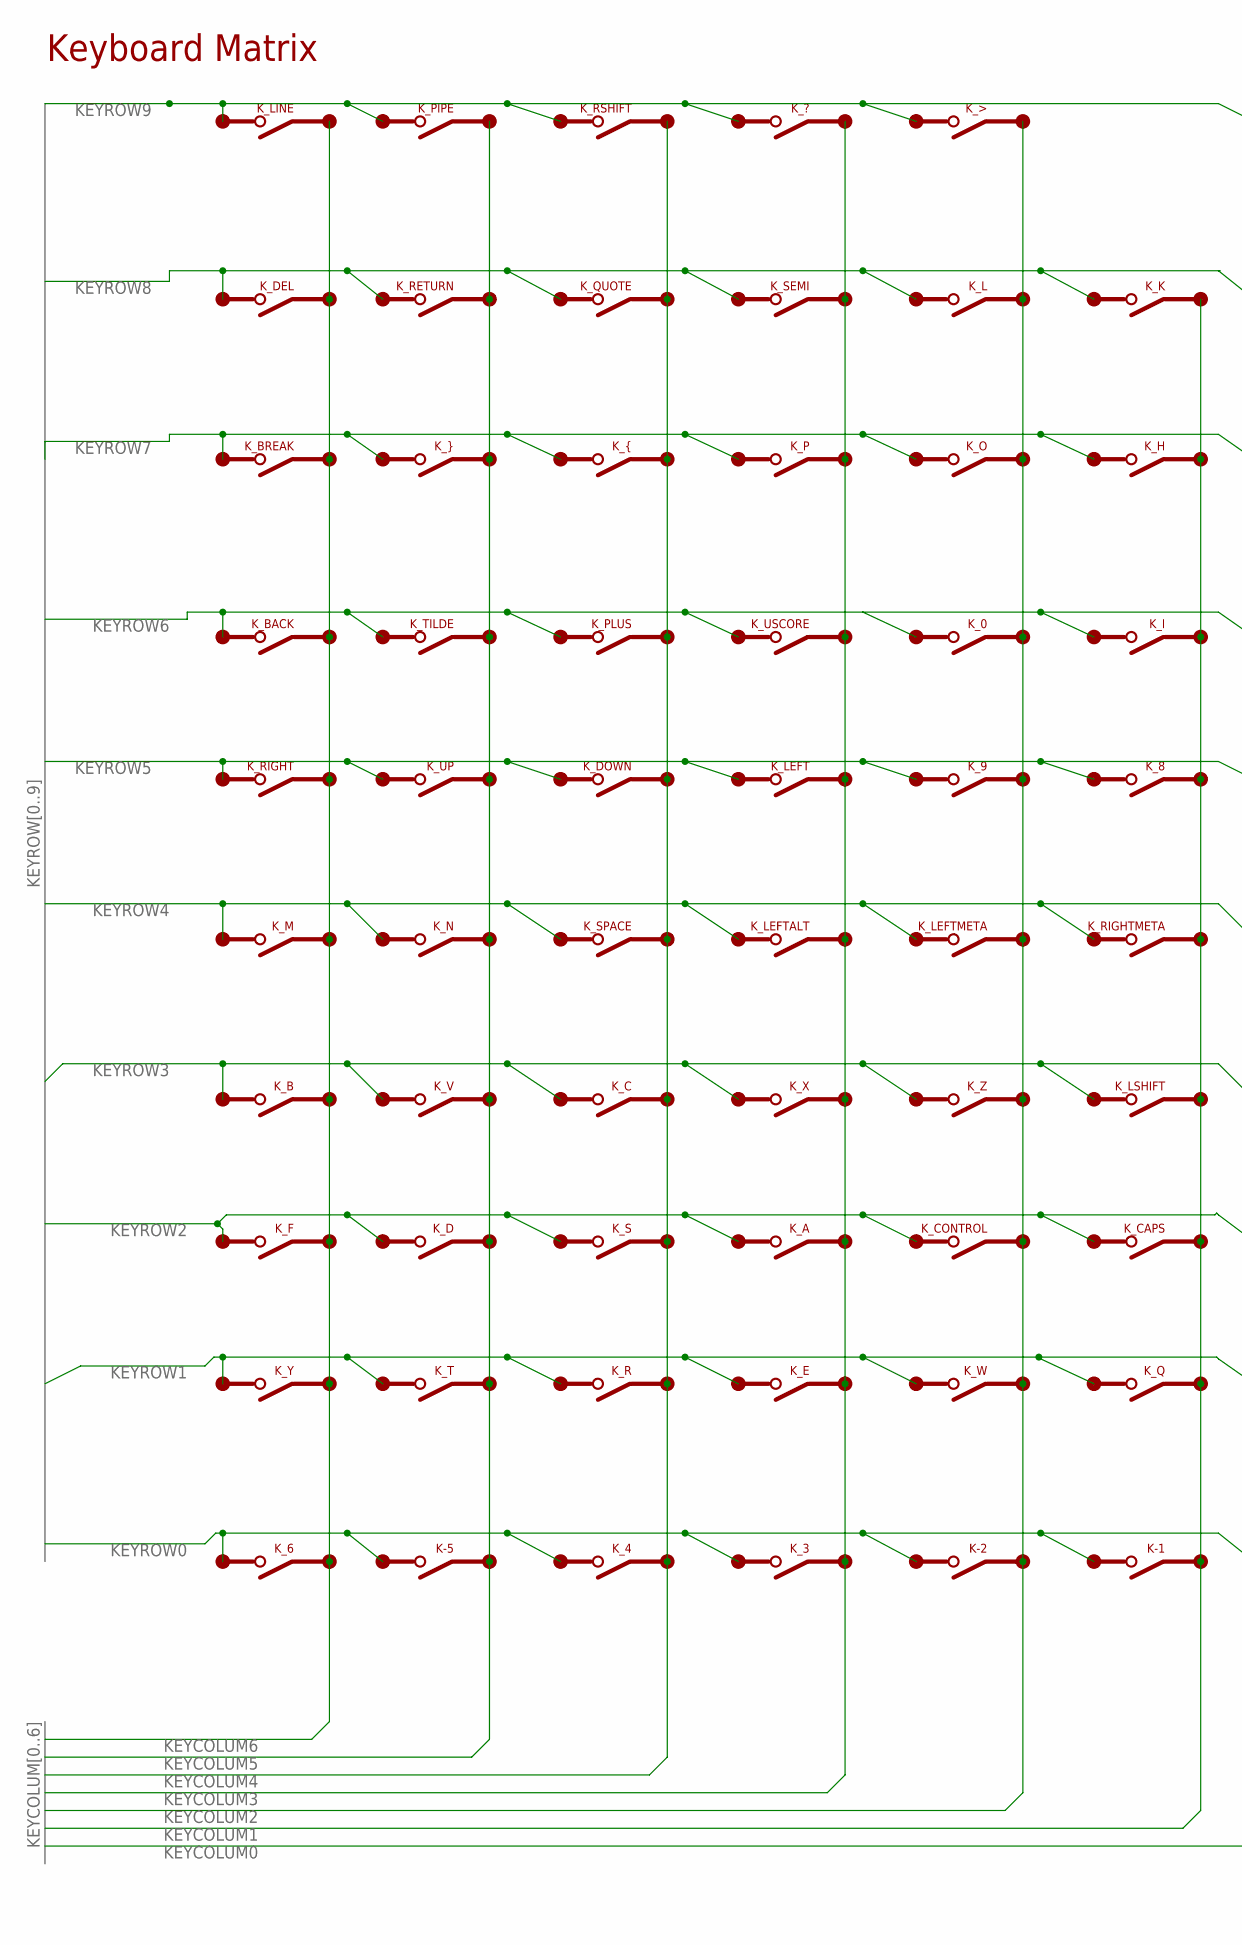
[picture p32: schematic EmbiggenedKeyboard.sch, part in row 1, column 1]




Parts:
0, 1, 2, 3, 4, 5, 6, 7, 8, 9: KEYSWITCH-PLAIN-MX-1U; MX-1U
A: KEYSWITCH-PLAIN-MX-1U; MX-1U
ALT, ALT2: KEYSWITCH-PLAIN-MX-1U; MX-1U
B: KEYSWITCH-PLAIN-MX-1U; MX-1U
BACK: KEYSWITCH-PLAIN-MX-1U; MX-1U
BRK: KEYSWITCH-PLAIN-MX-1U; MX-1U
C: KEYSWITCH-PLAIN-MX-1U; MX-1U
CAPS: KEYSWITCH-PLAIN-MX-1U; MX-1U
COMMA: KEYSWITCH-PLAIN-MX-1U; MX-1U
CTRL: KEYSWITCH-PLAIN-MX-1U; MX-1U
D: KEYSWITCH-PLAIN-MX-1U; MX-1U
DEL: KEYSWITCH-PLAIN-MX-1U; MX-1U
DOWN: KEYSWITCH-PLAIN-MX-1U; MX-1U
E: KEYSWITCH-PLAIN-MX-1U; MX-1U
EQUAL: KEYSWITCH-PLAIN-MX-1U; MX-1U
ESC: KEYSWITCH-PLAIN-MX-1U; MX-1U
F: KEYSWITCH-PLAIN-MX-1U; MX-1U
G: KEYSWITCH-PLAIN-MX-1U; MX-1U
GRAVE: KEYSWITCH-PLAIN-MX-1U; MX-1U
H: KEYSWITCH-PLAIN-MX-1U; MX-1U
I: KEYSWITCH-PLAIN-MX-1U; MX-1U
J: KEYSWITCH-PLAIN-MX-1U; MX-1U
K: KEYSWITCH-PLAIN-MX-1U; MX-1U
K-1, K-2, K-5: 1U_PAD; SILICONE_SWITCH
KP_DASH: KEYSWITCH-PLAIN-MX-1U; MX-1U
K_0, K_3, K_4, K_6, K_7, K_8, K_9: 1U_PAD; SILICONE_SWITCH
K_<: 1U_PAD; SILICONE_SWITCH
K_>: 1U_PAD; SILICONE_SWITCH
K_?: 1U_PAD; SILICONE_SWITCH
K_A: 1U_PAD; SILICONE_SWITCH
K_B: 1U_PAD; SILICONE_SWITCH
K_BACK: 1U_PAD; SILICONE_SWITCH
K_BREAK: 1U_PAD; SILICONE_SWITCH
K_C: 1U_PAD; SILICONE_SWITCH
K_CAPS: 1U_PAD; SILICONE_SWITCH
K_CONTROL: 2U_PAD; SILICONE_SWITCH_2U
K_D: 1U_PAD; SILICONE_SWITCH
K_DEL: 1U_PAD; SILICONE_SWITCH
K_DOWN: 1U_PAD; SILICONE_SWITCH
K_E: 1U_PAD; SILICONE_SWITCH
K_ESC: 1U_PAD; SILICONE_SWITCH
K_F: 1U_PAD; SILICONE_SWITCH
K_G: 1U_PAD; SILICONE_SWITCH
K_H: 1U_PAD; SILICONE_SWITCH
K_I: 1U_PAD; SILICONE_SWITCH
K_J: 1U_PAD; SILICONE_SWITCH
K_K: 1U_PAD; SILICONE_SWITCH
K_L: 1U_PAD; SILICONE_SWITCH
K_LEFT: 1U_PAD; SILICONE_SWITCH
K_LEFTALT: 1U_PAD; SILICONE_SWITCH
K_LEFTMETA: 1U_PAD; SILICONE_SWITCH
K_LINE: 1U_PAD; SILICONE_SWITCH
K_LSHIFT: 2U_PAD; SILICONE_SWITCH_2U
K_M: 1U_PAD; SILICONE_SWITCH
K_N: 1U_PAD; SILICONE_SWITCH
K_NOSCL: 1U_PAD; SILICONE_SWITCH
K_O: 1U_PAD; SILICONE_SWITCH
K_P: 1U_PAD; SILICONE_SWITCH
K_PIPE: 1U_PAD; SILICONE_SWITCH
K_PLUS: 1U_PAD; SILICONE_SWITCH
K_Q: 1U_PAD; SILICONE_SWITCH
K_QUOTE: 1U_PAD; SILICONE_SWITCH
K_R: 1U_PAD; SILICONE_SWITCH
K_RETURN: RETURN_PAD; SILICONE_RETURN
K_RIGHT: 1U_PAD; SILICONE_SWITCH
K_RIGHTALT: 1U_PAD; SILICONE_SWITCH
K_RIGHTMETA: 1U_PAD; SILICONE_SWITCH
K_RSHIFT: 2U_PAD; SILICONE_SWITCH_2U
K_S: 1U_PAD; SILICONE_SWITCH
K_SEMI: 1U_PAD; SILICONE_SWITCH
K_SETUP: 2U_PAD; SILICONE_SWITCH_2U
K_SPACE: SPACE_PAD; SILICONE_SPACE
K_T: 1U_PAD; SILICONE_SWITCH
K_TAB: 1U_PAD; SILICONE_SWITCH
K_TILDE: 1U_PAD; SILICONE_SWITCH
K_U: 1U_PAD; SILICONE_SWITCH
K_UP: 1U_PAD; SILICONE_SWITCH
K_USCORE: 1U_PAD; SILICONE_SWITCH
K_V: 1U_PAD; SILICONE_SWITCH
K_W: 1U_PAD; SILICONE_SWITCH
K_X: 1U_PAD; SILICONE_SWITCH
K_Y: 1U_PAD; SILICONE_SWITCH
K_Z: 1U_PAD; SILICONE_SWITCH
K_{: 1U_PAD; SILICONE_SWITCH
K_}: 1U_PAD; SILICONE_SWITCH
L: KEYSWITCH-PLAIN-MX-1U; MX-1U
LBRACKET: KEYSWITCH-PLAIN-MX-1U; MX-1U
LEFT: KEYSWITCH-PLAIN-MX-1U; MX-1U
LINE: KEYSWITCH-PLAIN-MX-1U; MX-1U
M: KEYSWITCH-PLAIN-MX-1U; MX-1U
META, META2: KEYSWITCH-PLAIN-MX-1U; MX-1U
N: KEYSWITCH-PLAIN-MX-1U; MX-1U
NO: KEYSWITCH-PLAIN-MX-1U; MX-1U
O: KEYSWITCH-PLAIN-MX-1U; MX-1U
P: KEYSWITCH-PLAIN-MX-1U; MX-1U
PERIOD: KEYSWITCH-PLAIN-MX-1U; MX-1U
Q: KEYSWITCH-PLAIN-MX-1U; MX-1U
QUOTE: KEYSWITCH-PLAIN-MX-1U; MX-1U
R: KEYSWITCH-PLAIN-MX-1U; MX-1U
RBRACKET: KEYSWITCH-PLAIN-MX-1U; MX-1U
RIGHT: KEYSWITCH-PLAIN-MX-1U; MX-1U
S: KEYSWITCH-PLAIN-MX-1U; MX-1U
SEMI: KEYSWITCH-PLAIN-MX-1U; MX-1U
SHIFT, SHIFT2: KEYSWITCH-PLAIN-MX-1U; MX-1U
SPACE, SPACE2, SPACE3: KEYSWITCH-PLAIN-MX-1U; MX-1U
T: KEYSWITCH-PLAIN-MX-1U; MX-1U
TAB: KEYSWITCH-PLAIN-MX-1U; MX-1U
U: KEYSWITCH-PLAIN-MX-1U; MX-1U
UP: KEYSWITCH-PLAIN-MX-1U; MX-1U
V: KEYSWITCH-PLAIN-MX-1U; MX-1U
W: KEYSWITCH-PLAIN-MX-1U; MX-1U
X: KEYSWITCH-PLAIN-MX-1U; MX-1U
Y: KEYSWITCH-PLAIN-MX-1U; MX-1U
Z: KEYSWITCH-PLAIN-MX-1U; MX-1U
\|: KEYSWITCH-PLAIN-MX-1U; MX-1U

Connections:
KEYCOLUM0: K_7.P$2, K_<.P$2, K_ESC.P$2, K_G.P$2, K_J.P$2, K_NOSCL.P$2, K_RIGHTALT.P$2, K_SETUP.P$2, K_TAB.P$2, K_U.P$2
KEYCOLUM1: K-1.P$2, K_8.P$2, K_CAPS.P$2, K_H.P$2, K_I.P$2, K_K.P$2, K_LSHIFT.P$2, K_Q.P$2, K_RIGHTMETA.P$2
KEYCOLUM2: K-2.P$2, K_0.P$2, K_9.P$2, K_>.P$2, K_CONTROL.P$2, K_L.P$2, K_LEFTMETA.P$2, K_O.P$2, K_W.P$2, K_Z.P$2
KEYCOLUM3: K_3.P$2, K_?.P$2, K_A.P$2, K_E.P$2, K_LEFT.P$2, K_LEFTALT.P$2, K_P.P$2, K_SEMI.P$2, K_USCORE.P$2, K_X.P$2
KEYCOLUM4: K_4.P$2, K_C.P$2, K_DOWN.P$2, K_PLUS.P$2, K_QUOTE.P$2, K_R.P$2, K_RSHIFT.P$2, K_S.P$2, K_SPACE.P$2, K_{.P$2
KEYCOLUM5: K-5.P$2, K_D.P$2, K_N.P$2, K_PIPE.P$2, K_RETURN.P$2, K_T.P$2, K_TILDE.P$2, K_UP.P$2, K_V.P$2, K_}.P$2
KEYCOLUM6: K_6.P$2, K_B.P$2, K_BACK.P$2, K_BREAK.P$2, K_DEL.P$2, K_F.P$2, K_LINE.P$2, K_M.P$2, K_RIGHT.P$2, K_Y.P$2
KEYROW0: K-1.P$1, K-2.P$1, K-5.P$1, K_3.P$1, K_4.P$1, K_6.P$1, K_ESC.P$1
KEYROW1: K_E.P$1, K_Q.P$1, K_R.P$1, K_SETUP.P$1, K_T.P$1, K_W.P$1, K_Y.P$1
KEYROW2: K_A.P$1, K_CAPS.P$1, K_CONTROL.P$1, K_D.P$1, K_F.P$1, K_S.P$1, K_TAB.P$1
KEYROW3: K_B.P$1, K_C.P$1, K_LSHIFT.P$1, K_NOSCL.P$1, K_V.P$1, K_X.P$1, K_Z.P$1
KEYROW4: K_LEFTALT.P$1, K_LEFTMETA.P$1, K_M.P$1, K_N.P$1, K_RIGHTALT.P$1, K_RIGHTMETA.P$1, K_SPACE.P$1
KEYROW5: K_7.P$1, K_8.P$1, K_9.P$1, K_DOWN.P$1, K_LEFT.P$1, K_RIGHT.P$1, K_UP.P$1
KEYROW6: K_0.P$1, K_BACK.P$1, K_I.P$1, K_PLUS.P$1, K_TILDE.P$1, K_U.P$1, K_USCORE.P$1
KEYROW7: K_BREAK.P$1, K_G.P$1, K_H.P$1, K_O.P$1, K_P.P$1, K_{.P$1, K_}.P$1
KEYROW8: K_DEL.P$1, K_J.P$1, K_K.P$1, K_L.P$1, K_QUOTE.P$1, K_RETURN.P$1, K_SEMI.P$1
KEYROW9: K_<.P$1, K_>.P$1, K_?.P$1, K_LINE.P$1, K_PIPE.P$1, K_RSHIFT.P$1

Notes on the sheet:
Keyboard Matrix

Board: 2 copper layers, 137 parts (0 on the bottom side), 17 nets, no tracks yet.

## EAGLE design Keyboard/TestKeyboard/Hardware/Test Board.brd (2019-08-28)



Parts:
K-1, K-2, K-5: 1U_PAD; SILICONE_SWITCH
K_0, K_3, K_4, K_6, K_7, K_8, K_9: 1U_PAD; SILICONE_SWITCH
K_<: 1U_PAD; SILICONE_SWITCH
K_>: 1U_PAD; SILICONE_SWITCH
K_?: 1U_PAD; SILICONE_SWITCH
K_A: 1U_PAD; SILICONE_SWITCH
K_B: 1U_PAD; SILICONE_SWITCH
K_BACK: 1U_PAD; SILICONE_SWITCH
K_BREAK: 1U_PAD; SILICONE_SWITCH
K_C: 1U_PAD; SILICONE_SWITCH
K_CAPS: 1U_PAD; SILICONE_SWITCH
K_CONTROL: 2U_PAD; SILICONE_SWITCH_2U
K_D: 1U_PAD; SILICONE_SWITCH
K_DEL: 1U_PAD; SILICONE_SWITCH
K_DOWN: 1U_PAD; SILICONE_SWITCH
K_E: 1U_PAD; SILICONE_SWITCH
K_ESC: 1U_PAD; SILICONE_SWITCH
K_F: 1U_PAD; SILICONE_SWITCH
K_G: 1U_PAD; SILICONE_SWITCH
K_H: 1U_PAD; SILICONE_SWITCH
K_I: 1U_PAD; SILICONE_SWITCH
K_J: 1U_PAD; SILICONE_SWITCH
K_K: 1U_PAD; SILICONE_SWITCH
K_L: 1U_PAD; SILICONE_SWITCH
K_LEFT: 1U_PAD; SILICONE_SWITCH
K_LEFTALT: 1U_PAD; SILICONE_SWITCH
K_LEFTMETA: 1U_PAD; SILICONE_SWITCH
K_LINE: 1U_PAD; SILICONE_SWITCH
K_LSHIFT: 2U_PAD; SILICONE_SWITCH_2U
K_M: 1U_PAD; SILICONE_SWITCH
K_N: 1U_PAD; SILICONE_SWITCH
K_NOSCL: 1U_PAD; SILICONE_SWITCH
K_O: 1U_PAD; SILICONE_SWITCH
K_P: 1U_PAD; SILICONE_SWITCH
K_PIPE: 1U_PAD; SILICONE_SWITCH
K_PLUS: 1U_PAD; SILICONE_SWITCH
K_Q: 1U_PAD; SILICONE_SWITCH
K_QUOTE: 1U_PAD; SILICONE_SWITCH
K_R: 1U_PAD; SILICONE_SWITCH
K_RETURN: RETURN_PAD; SILICONE_RETURN
K_RIGHT: 1U_PAD; SILICONE_SWITCH
K_RIGHTALT: 1U_PAD; SILICONE_SWITCH
K_RIGHTMETA: 1U_PAD; SILICONE_SWITCH
K_RSHIFT: 2U_PAD; SILICONE_SWITCH_2U
K_S: 1U_PAD; SILICONE_SWITCH
K_SEMI: 1U_PAD; SILICONE_SWITCH
K_SETUP: 2U_PAD; SILICONE_SWITCH_2U
K_SPACE: SPACE_PAD; SILICONE_SPACE
K_T: 1U_PAD; SILICONE_SWITCH
K_TAB: 1U_PAD; SILICONE_SWITCH
K_TILDE: 1U_PAD; SILICONE_SWITCH
K_U: 1U_PAD; SILICONE_SWITCH
K_UP: 1U_PAD; SILICONE_SWITCH
K_USCORE: 1U_PAD; SILICONE_SWITCH
K_V: 1U_PAD; SILICONE_SWITCH
K_W: 1U_PAD; SILICONE_SWITCH
K_X: 1U_PAD; SILICONE_SWITCH
K_Y: 1U_PAD; SILICONE_SWITCH
K_Z: 1U_PAD; SILICONE_SWITCH
K_{: 1U_PAD; SILICONE_SWITCH
K_}: 1U_PAD; SILICONE_SWITCH
U$1: TEENSYLC; 2X14

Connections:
KEYCOLUMN0: K_ESC.P$2, K_RIGHTALT.P$2, K_SETUP.P$2, U$1.0
KEYCOLUMN1: K-1.P$2, K_CAPS.P$2, K_NOSCL.P$2, K_RIGHTMETA.P$2, K_TAB.P$2, U$1.1
KEYCOLUMN2: K-2.P$2, K_CONTROL.P$2, K_Q.P$2, U$1.2
KEYCOLUMN3: K_3.P$2, K_A.P$2, K_LEFTMETA.P$2, K_LSHIFT.P$2, K_W.P$2, U$1.3
KEYCOLUMN4: K_4.P$2, K_E.P$2, K_LEFTALT.P$2, K_S.P$2, K_Z.P$2, U$1.4
KEYCOLUMN5: K-5.P$2, K_D.P$2, K_R.P$2, K_SPACE.P$1, K_X.P$2, U$1.5
KEYCOLUMN6: K_6.P$2, K_C.P$2, K_F.P$2, K_T.P$2, U$1.6
KEYCOLUMN7: K_7.P$2, K_G.P$2, K_V.P$2, K_Y.P$2, U$1.7
KEYCOLUMN8: K_8.P$2, K_B.P$2, K_H.P$2, K_U.P$2, U$1.8
KEYCOLUMN9: K_9.P$2, K_I.P$2, K_J.P$2, K_N.P$2, U$1.9
KEYCOLUMN10: K_0.P$2, K_K.P$2, K_M.P$2, K_O.P$2, U$1.10
KEYCOLUMN11: K_<.P$2, K_L.P$2, K_P.P$2, K_USCORE.P$2, U$1.11
KEYCOLUMN12: K_>.P$2, K_LEFT.P$2, K_PLUS.P$2, K_SEMI.P$2, K_{.P$2, U$1.12
KEYCOLUMN13: K_?.P$2, K_DOWN.P$2, K_QUOTE.P$2, K_TILDE.P$2, K_}.P$2, U$1.13
KEYCOLUMN14: K_BACK.P$2, K_RETURN.P$1, K_RSHIFT.P$1, K_UP.P$2, U$1.14
KEYCOLUMN15: K_BREAK.P$2, K_DEL.P$2, K_LINE.P$2, K_PIPE.P$2, K_RIGHT.P$2, U$1.15
KEYROW0: K-1.P$1, K-2.P$1, K-5.P$1, K_3.P$1, K_4.P$1, K_6.P$1, K_7.P$1, K_8.P$1, K_DOWN.P$1, K_ESC.P$1, K_LEFT.P$1, K_RIGHT.P$1, K_UP.P$1, U$1.19
KEYROW1: K_0.P$1, K_9.P$1, K_BACK.P$1, K_BREAK.P$1, K_E.P$1, K_PLUS.P$1, K_Q.P$1, K_R.P$1, K_SETUP.P$1, K_T.P$1, K_TAB.P$1, K_TILDE.P$1, K_U.P$1, K_USCORE.P$1, K_W.P$1, K_Y.P$1, U$1.20
KEYROW2: K_A.P$1, K_CAPS.P$1, K_CONTROL.P$1, K_D.P$1, K_DEL.P$1, K_F.P$1, K_G.P$1, K_H.P$1, K_I.P$1, K_O.P$1, K_P.P$1, K_RETURN.P$2, K_S.P$1, K_{.P$1, K_}.P$1, U$1.21
KEYROW3: K_B.P$1, K_C.P$1, K_J.P$1, K_K.P$1, K_L.P$1, K_LSHIFT.P$1, K_NOSCL.P$1, K_PIPE.P$1, K_QUOTE.P$1, K_RSHIFT.P$2, K_SEMI.P$1, K_V.P$1, K_X.P$1, K_Z.P$1, U$1.22
KEYROW4: K_<.P$1, K_>.P$1, K_?.P$1, K_LEFTALT.P$1, K_LEFTMETA.P$1, K_LINE.P$1, K_M.P$1, K_N.P$1, K_RIGHTALT.P$1, K_RIGHTMETA.P$1, K_SPACE.P$2, U$1.23

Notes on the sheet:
Row 1
Row 2
Row 3
Row 4
Row 0
right arrow
up arrow
down arrow
left arrow
esc
setup
tab
U_score
back
break
del
return
Control
Caps
Pipe
r shift
quote
semi;
Lshift
Noscl
Line
Space
Left Alt
Left Meta
Right Meta
RightAlt
Teensy LC


Board: 2 copper layers, 160.1 x 85.1 mm, 70 parts (0 on the bottom side), 21 nets.

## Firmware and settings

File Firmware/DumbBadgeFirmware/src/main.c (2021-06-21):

/**************************This is 80 width line*******************************/
#include <asf.h>
#include <string.h>

#include <stdio.h>
#include <stdlib.h>
#include <stdint.h>
#include <stddef.h>
#include <stdbool.h>
#include <assert.h>


#include "settings.h"
#include "globals.h"

#include "LCDBus.h"
#include "LCD.h"
#include "keyboard.h"
#include "console.h"
#include "splash.h"
#include "uart.h"
#include "ouroboros.h"
#include "settings.h"
#include "parser.h"
#include "parserState.h"


//#include "config_usart.h"
#include "conf_clocks.h"

/** VARIABLES *****************************************************************/

//Version Label
char compileTime[] =  __TIMESTAMP__;
char versionLabel[] = "Beach Taco Bell";

#define UART_BUFFER_SIZE 100

uint16_t ul_tickcount=0;
bool funcLock = false;
uint8_t rx_buf;

parserState currentState = stateGround;


/** GLOBAL SETTINGS ***********************************************************/

bool localEcho = true;
bool breakEnable = false;
bool lineFeed = true;
bool autoWrap = true;
int lineFeedNewLine = 1;

//This device is for gamers because all the characters are white by default.
uint16_t defaultForegroundColor = 0xFFFF; 
uint16_t defaultBackgroundColor = 0x0000;


/** LOCAL PROTOTYPES **********************************************************/

void usart_read_callback(struct usart_module *const usart_module);
void configure_usart(void);
void configure_usart_callbacks(void);

void setupBoard(void);
//void configure_usart_USB(void);
void configure_adc(void);
void conf_systick(void);


//struct usart_module usart_USB;
struct adc_module adc_instance;
struct usart_module usart_instance;
cbuf_handle_t ouroboros;
//struct Settings settings;


#define IS_MTB_ENABLED \
        REG_MTB_MASTER & MTB_MASTER_EN
#define DISABLE_MTB \
        REG_MTB_MASTER = REG_MTB_MASTER & ~MTB_MASTER_EN
#define ENABLE_MTB \
        REG_MTB_MASTER = REG_MTB_MASTER | MTB_MASTER_EN

__attribute__((aligned(1024)))
volatile char __tracebuffer__[1024];
volatile int __tracebuffersize__ = sizeof(__tracebuffer__);

void InitTraceBuffer()
{
    int index = 0;
    uint32_t mtbEnabled = IS_MTB_ENABLED;
    DISABLE_MTB;
    for(index =0; index<1024; index++)
    {
        __tracebuffer__[index];
        __tracebuffersize__;
    }
    if(mtbEnabled)
        ENABLE_MTB;
}


/** STUFF BEGINS HERE *********************************************************/
int main (void)
{
	InitTraceBuffer();
	
	setupBoard();

	//initialize the settings	
	//settings.localEcho=false;

	//initialize the ring buffer for uart
	uint8_t * buffer  = malloc(UART_BUFFER_SIZE * sizeof(uint8_t));
	ouroboros = ring_init(buffer, UART_BUFFER_SIZE);
	


	while(1)
	{			
		__WFI();
		
		if((ul_tickcount % (UINT16_MAX/2) == 0) && (funcLock == false))
		{
			funcLock = true;

			blinkCursor();
			
			funcLock = false;
			
		}
		
		if((ul_tickcount % 200 == 0) && (funcLock == false))
		{
			funcLock = true;

			readKeyboard();
			
			printKeyboardBuffer();

			parseRXBuffer();
			funcLock = false;
		}
		
	
	}
}

/**************************INTERRUPT STUFF****************************/

void SysTick_Handler(void)
{
	ul_tickcount++;
	
	if(ul_tickcount == UINT16_MAX-1)
		ul_tickcount = 0;
}

void conf_systick(void)
{
	
	//system_core_clk=48Mhz / 1000=48kHz systic clk if 48Mhz  is used
	SysTick_Config(SystemCoreClock/1000);
	system_interrupt_enable(SYSTEM_INTERRUPT_SYSTICK);
}

void usart_read_callback(struct usart_module *const usart_module)
{

	//Read one character from the UART.
	//We can only use this function because it's non-blocking
	//and we can only read one character because reading > 1 means
	//it doesn't complete until _all_ characters are read.
	
	usart_read_buffer_job(&usart_instance, (uint8_t*)&rx_buf, 1);
	
	//stuff that ONE CHARACTER into the circular FIFO buffer
	ring_put(ouroboros, rx_buf);
}


/**************************SERCOM STUFF*******************************/


void configure_usart(void)
{
	struct usart_config config_usart;
	usart_get_config_defaults(&config_usart);

	config_usart.baudrate    = 9600;
	config_usart.mux_setting = USART_RX_1_TX_0_XCK_1;
	config_usart.pinmux_pad0 = PINMUX_PA08D_SERCOM2_PAD0;
	config_usart.pinmux_pad1 = PINMUX_PA09D_SERCOM2_PAD1;
	config_usart.pinmux_pad2 = PINMUX_UNUSED;
	config_usart.pinmux_pad3 = PINMUX_UNUSED;
	
	/*
	The SamD51 version will be using CTS and RTS flow control;
	see this for more information:
	
	https://www.avrfreaks.net/forum/no-asf-samd21-sercom-usart-rxc-interrupt-not-triggering
	
	RTS on PAD2 and CTS on PAD3
	
	*/
	
	while (usart_init(&usart_instance, SERCOM2, &config_usart) != STATUS_OK) {
	}
	stdio_serial_init(&usart_instance, SERCOM2, &config_usart);
	usart_enable(&usart_instance);
}

void configure_usart_callbacks(void)
{
	usart_register_callback(&usart_instance,usart_read_callback, USART_CALLBACK_BUFFER_RECEIVED);
	usart_enable_callback(&usart_instance, USART_CALLBACK_BUFFER_RECEIVED);
}




/*
void configure_usart_USB(void)
{
	struct usart_config config_usart_USB;
	usart_get_config_defaults(&config_usart_USB);

		config_usart_USB.baudrate    = 9600;
		config_usart_USB.mux_setting = EDBG_CDC_SERCOM_MUX_SETTING;
		config_usart_USB.pinmux_pad0 = EDBG_CDC_SERCOM_PINMUX_PAD0;
		config_usart_USB.pinmux_pad1 = EDBG_CDC_SERCOM_PINMUX_PAD1;
		config_usart_USB.pinmux_pad2 = EDBG_CDC_SERCOM_PINMUX_PAD2;
		config_usart_USB.pinmux_pad3 = EDBG_CDC_SERCOM_PINMUX_PAD3;
		while (usart_init(&usart_USB,
		EDBG_CDC_MODULE, &config_usart_USB) != STATUS_OK) {
		}

	usart_enable(&usart_USB);
}
*/

void configure_adc(void)
{
	struct adc_config config_adc;
	adc_get_config_defaults(&config_adc);
	config_adc.clock_source = GCLK_GENERATOR_1;
	config_adc.clock_prescaler = ADC_CLOCK_PRESCALER_DIV16;
	config_adc.reference = ADC_REFERENCE_INT1V;
	config_adc.positive_input = ADC_POSITIVE_INPUT_TEMP;
	config_adc.negative_input = ADC_NEGATIVE_INPUT_GND;
	adc_init(&adc_instance, ADC, &config_adc);
	adc_enable(&adc_instance);
}


void setupBoard(void)
{
	uint16_t adcResult;
	uint16_t megaHurtz = (uint16_t)system_gclk_gen_get_hz(0);
	
	
	system_init();
	
	delay_init();
		
	conf_systick();
	
	InitLCD();
	splashScreen();
	
	configure_adc();
	adc_start_conversion(&adc_instance);
	do {
	/* Wait for conversion to be done and read out result */
	} while (adc_read(&adc_instance, &adcResult) == STATUS_BUSY);
	
	
	srand((adcResult ^ megaHurtz));
	

	
	//InitLCD();
	//splashScreen();
	
	//configure_usart_USB();
	
	/*
	The Pi is connected to a different SERCOM in the SAMD51 version;
	The Pi is now connected to SERCOM2, with PAD0 (PI_TX) on pin 46,
	and PAD1 (PI_RX) on pin 47.
	
	Also, this gives us the ability to bridge UARTs. THIS IS COOL
	
	*/
	configure_usart();
	configure_usart_callbacks();
	system_interrupt_enable_global();
	
	//I have no idea why I need to call this; it's in the callback and it
	//doesn't work without this line here. Remove this at your own peril.
	usart_read_buffer_job(&usart_instance, (uint8_t*)&rx_buf, 1);
	
	printf("\n\rSerial OK 9600 8N1\n\r");
	
	conf_systick();

	xCharPos=0;
	yCharPos=0;
	drawChar(0xFF);
}

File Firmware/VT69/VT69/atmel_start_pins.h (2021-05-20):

/*
 * Code generated from Atmel Start.
 *
 * This file will be overwritten when reconfiguring your Atmel Start project.
 * Please copy examples or other code you want to keep to a separate file
 * to avoid losing it when reconfiguring.
 */
#ifndef ATMEL_START_PINS_H_INCLUDED
#define ATMEL_START_PINS_H_INCLUDED


// SAMD51 has 14 pin functions

#define GPIO_PIN_FUNCTION_A 0
#define GPIO_PIN_FUNCTION_B 1
#define GPIO_PIN_FUNCTION_C 2
#define GPIO_PIN_FUNCTION_D 3
#define GPIO_PIN_FUNCTION_E 4
#define GPIO_PIN_FUNCTION_F 5
#define GPIO_PIN_FUNCTION_G 6
#define GPIO_PIN_FUNCTION_H 7
#define GPIO_PIN_FUNCTION_I 8
#define GPIO_PIN_FUNCTION_J 9
#define GPIO_PIN_FUNCTION_K 10
#define GPIO_PIN_FUNCTION_L 11
#define GPIO_PIN_FUNCTION_M 12
#define GPIO_PIN_FUNCTION_N 13

#define PA00 GPIO(GPIO_PORTA, 0)
#define PA01 GPIO(GPIO_PORTA, 1)
#define PA02 GPIO(GPIO_PORTA, 2)
#define PA03 GPIO(GPIO_PORTA, 3)
#define PA04 GPIO(GPIO_PORTA, 4)
#define PA05 GPIO(GPIO_PORTA, 5)
#define PA06 GPIO(GPIO_PORTA, 6)
#define PA07 GPIO(GPIO_PORTA, 7)
#define PA08 GPIO(GPIO_PORTA, 8)
#define PA09 GPIO(GPIO_PORTA, 9)
#define PA10 GPIO(GPIO_PORTA, 10)
#define PA11 GPIO(GPIO_PORTA, 11)
#define PA12 GPIO(GPIO_PORTA, 12)
#define PA13 GPIO(GPIO_PORTA, 13)
#define PA14 GPIO(GPIO_PORTA, 14)
#define PA15 GPIO(GPIO_PORTA, 15)
#define PA16 GPIO(GPIO_PORTA, 16)
#define PA17 GPIO(GPIO_PORTA, 17)
#define PA18 GPIO(GPIO_PORTA, 18)
#define PA19 GPIO(GPIO_PORTA, 19)
#define PA20 GPIO(GPIO_PORTA, 20)
#define PA21 GPIO(GPIO_PORTA, 21)
#define PA22 GPIO(GPIO_PORTA, 22)
#define PA23 GPIO(GPIO_PORTA, 23)
#define PA24 GPIO(GPIO_PORTA, 24)
#define PA25 GPIO(GPIO_PORTA, 25)
#define PA27 GPIO(GPIO_PORTA, 27)
#define PA30 GPIO(GPIO_PORTA, 30)
#define PA31 GPIO(GPIO_PORTA, 31)

#define PB00 GPIO(GPIO_PORTB, 0)
#define PB01 GPIO(GPIO_PORTB, 1)
#define PB02 GPIO(GPIO_PORTB, 2)
#define PB03 GPIO(GPIO_PORTB, 3)
#define PB04 GPIO(GPIO_PORTB, 4)
#define PB05 GPIO(GPIO_PORTB, 5)
#define PB06 GPIO(GPIO_PORTB, 6)
#define PB07 GPIO(GPIO_PORTB, 7)
#define PB08 GPIO(GPIO_PORTB, 8)
#define PB09 GPIO(GPIO_PORTB, 9)
#define PB10 GPIO(GPIO_PORTB, 10)
#define PB11 GPIO(GPIO_PORTB, 11)
#define PB12 GPIO(GPIO_PORTB, 12)
#define PB13 GPIO(GPIO_PORTB, 13)
#define PB14 GPIO(GPIO_PORTB, 14)
#define PB15 GPIO(GPIO_PORTB, 15)
#define PB16 GPIO(GPIO_PORTB, 16)
#define PB17 GPIO(GPIO_PORTB, 17)
#define PB18 GPIO(GPIO_PORTB, 18)
#define PB19 GPIO(GPIO_PORTB, 19)
#define PB20 GPIO(GPIO_PORTB, 20)
#define PB21 GPIO(GPIO_PORTB, 21)
#define PB22 GPIO(GPIO_PORTB, 22)
#define PB23 GPIO(GPIO_PORTB, 23)
#define PB24 GPIO(GPIO_PORTB, 24)
#define PB25 GPIO(GPIO_PORTB, 25)
#define PB30 GPIO(GPIO_PORTB, 30)
#define PB31 GPIO(GPIO_PORTB, 31)

#define PC00 GPIO(GPIO_PORTC, 0)
#define PC01 GPIO(GPIO_PORTC, 1)
#define PC02 GPIO(GPIO_PORTC, 2)
#define PC03 GPIO(GPIO_PORTC, 3)
#define PC05 GPIO(GPIO_PORTC, 5)
#define PC06 GPIO(GPIO_PORTC, 6)
#define PC07 GPIO(GPIO_PORTC, 7)
#define PC10 GPIO(GPIO_PORTC, 10)
#define PC11 GPIO(GPIO_PORTC, 11)
#define PC12 GPIO(GPIO_PORTC, 12)
#define PC13 GPIO(GPIO_PORTC, 13)
#define PC14 GPIO(GPIO_PORTC, 14)
#define PC15 GPIO(GPIO_PORTC, 15)
#define PC16 GPIO(GPIO_PORTC, 16)
#define PC17 GPIO(GPIO_PORTC, 17)
#define PC18 GPIO(GPIO_PORTC, 18)
#define PC19 GPIO(GPIO_PORTC, 19)
#define PC20 GPIO(GPIO_PORTC, 20)
#define PC21 GPIO(GPIO_PORTC, 21)
#define PC24 GPIO(GPIO_PORTC, 24)
#define PC25 GPIO(GPIO_PORTC, 25)
#define PC26 GPIO(GPIO_PORTC, 26)
#define PC27 GPIO(GPIO_PORTC, 27)
#define PC28 GPIO(GPIO_PORTC, 28)

#endif // ATMEL_START_PINS_H_INCLUDED

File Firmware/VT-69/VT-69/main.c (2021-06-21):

/*
 * VT-69.c
 *
 * Created: 6/10/2021 11:07:04 AM
 * Author : bench
 */ 

#include "sam.h"

#include <stdio.h>

// Constants for Clock generators
#define GENERIC_CLOCK_GENERATOR_MAIN		(0u)
#define GENERIC_CLOCK_GENERATOR_XOSC32K		(3u)
#define GENERIC_CLOCK_GENERATOR_48M			(1u)
#define GENERIC_CLOCK_GENERATOR_48M_SYNC	GCLK_SYNCBUSY_GENCTRL1
#define GENERIC_CLOCK_GENERATOR_100M		(2u)
#define GENERIC_CLOCK_GENERATOR_100M_SYNC	GCLK_SYNCBUSY_GENCTRL2
#define GENERIC_CLOCK_GENERATOR_12M			(4u)
#define GENERIC_CLOCK_GENERATOR_12M_SYNC	GCLK_SYNCBUSY_GENCTRL4

//USE DPLL0 for 120MHZ
#define MAIN_CLOCK_SOURCE				  GCLK_GENCTRL_SRC_DPLL0

#define GENERIC_CLOCK_GENERATOR_1M		  (5u)



#define GENERIC_CLOCK_GENERATOR_OSC32K    (1u)
#define GENERIC_CLOCK_GENERATOR_OSCULP32K (2u) /* Initialized at reset for WDT */
#define GENERIC_CLOCK_GENERATOR_OSC8M     (3u)
// Constants for Clock multiplexers
#define GENERIC_CLOCK_MULTIPLEXER_DFLL48M (0u)

#define F_CPU 120000000

void SystemInit(void);

int main(void)
{
	
	SystemInit();
	
    /* Replace with your application code */
    while (1) 
    {
		
		
    }
}

void SystemInit(void)
{
		//Set NVM Read Wait States to 0
		NVMCTRL->CTRLA.reg |= NVMCTRL_CTRLA_RWS(0);
	
		//Enable XOSC32K clock (External on-board 32.768Hz oscillator)
		OSC32KCTRL->XOSC32K.reg = OSC32KCTRL_XOSC32K_ENABLE | OSC32KCTRL_XOSC32K_EN32K | OSC32KCTRL_XOSC32K_EN32K | OSC32KCTRL_XOSC32K_CGM_XT | OSC32KCTRL_XOSC32K_XTALEN;
		while( (OSC32KCTRL->STATUS.reg & OSC32KCTRL_STATUS_XOSC32KRDY) == 0 ){
			 /* Wait for oscillator to be ready */
		}
	
		//software reset 
		GCLK->CTRLA.bit.SWRST = 1;
		while ( GCLK->SYNCBUSY.reg & GCLK_SYNCBUSY_SWRST ){
			  /* wait for reset to complete */
		}
	
		//	Put XOSC32K as source of Generic Clock Generator 3
		GCLK->GENCTRL[GENERIC_CLOCK_GENERATOR_XOSC32K].reg = GCLK_GENCTRL_SRC(GCLK_GENCTRL_SRC_XOSC32K) | //generic clock gen 3
		GCLK_GENCTRL_GENEN;
	
		while ( GCLK->SYNCBUSY.reg & GCLK_SYNCBUSY_GENCTRL3 ){
			  /* Wait for synchronization */
		}
	
		 /* ----------------------------------------------------------------------------------------------
		 * 3) Put OSCULP32K as source for Generic Clock Generator 0
		 */
		GCLK->GENCTRL[0].reg = GCLK_GENCTRL_SRC(GCLK_GENCTRL_SRC_OSCULP32K) | GCLK_GENCTRL_GENEN;
	
	  /* ----------------------------------------------------------------------------------------------
	   * 4) Enable DFLL48M clock
	   */

	  while ( GCLK->SYNCBUSY.reg & GCLK_SYNCBUSY_GENCTRL0 ){
		/* Wait for synchronization */
	  }
  
	 /* DFLL Configuration in Open Loop mode */
 
	 OSCCTRL->DFLLCTRLA.reg = 0;
	 //GCLK->PCHCTRL[OSCCTRL_GCLK_ID_DFLL48].reg = (1 << GCLK_PCHCTRL_CHEN_Pos) | GCLK_PCHCTRL_GEN(GCLK_PCHCTRL_GEN_GCLK3_Val);
 
	 OSCCTRL->DFLLMUL.reg = OSCCTRL_DFLLMUL_CSTEP( 0x1 ) |
	 OSCCTRL_DFLLMUL_FSTEP( 0x1 ) |
	 OSCCTRL_DFLLMUL_MUL( 0 );
 
	 while ( OSCCTRL->DFLLSYNC.reg & OSCCTRL_DFLLSYNC_DFLLMUL )
	 {
		 /* Wait for synchronization */
	 }
 
	 OSCCTRL->DFLLCTRLB.reg = 0;
	 while ( OSCCTRL->DFLLSYNC.reg & OSCCTRL_DFLLSYNC_DFLLCTRLB )
	 {
		 /* Wait for synchronization */
	 }
 
	 OSCCTRL->DFLLCTRLA.reg |= OSCCTRL_DFLLCTRLA_ENABLE;
	 while ( OSCCTRL->DFLLSYNC.reg & OSCCTRL_DFLLSYNC_ENABLE )
	 {
		 /* Wait for synchronization */
	 }
 
	 OSCCTRL->DFLLVAL.reg = OSCCTRL->DFLLVAL.reg;
	 while( OSCCTRL->DFLLSYNC.bit.DFLLVAL );
 
	 OSCCTRL->DFLLCTRLB.reg = OSCCTRL_DFLLCTRLB_WAITLOCK |
	 OSCCTRL_DFLLCTRLB_CCDIS | OSCCTRL_DFLLCTRLB_USBCRM ;
 
	 while ( !OSCCTRL->STATUS.bit.DFLLRDY )
	 {
		 /* Wait for synchronization */
	 }
 
	 GCLK->GENCTRL[GENERIC_CLOCK_GENERATOR_1M].reg = GCLK_GENCTRL_SRC(GCLK_GENCTRL_SRC_DFLL_Val) | GCLK_GENCTRL_GENEN | GCLK_GENCTRL_DIV(48u);
 
	 while ( GCLK->SYNCBUSY.bit.GENCTRL5 ){
		 /* Wait for synchronization */
	 }
 
	 /* ------------------------------------------------------------------------
	  * Set up the PLLs
	  */
	
	  //PLL0 is 120MHz
	  GCLK->PCHCTRL[OSCCTRL_GCLK_ID_FDPLL0].reg = (1 << GCLK_PCHCTRL_CHEN_Pos) | GCLK_PCHCTRL_GEN(GCLK_PCHCTRL_GEN_GCLK5_Val);
  
	  // This rounds to nearest full-MHz increment; not currently using frac
	  OSCCTRL->Dpll[0].DPLLRATIO.reg = OSCCTRL_DPLLRATIO_LDRFRAC(0x00) | OSCCTRL_DPLLRATIO_LDR((F_CPU - 500000) / 1000000);
  
	  while(OSCCTRL->Dpll[0].DPLLSYNCBUSY.bit.DPLLRATIO);
  
	  //MUST USE LBYPASS DUE TO BUG IN REV A OF SAMD51
	  OSCCTRL->Dpll[0].DPLLCTRLB.reg = OSCCTRL_DPLLCTRLB_REFCLK_GCLK | OSCCTRL_DPLLCTRLB_LBYPASS;
  
	  OSCCTRL->Dpll[0].DPLLCTRLA.reg = OSCCTRL_DPLLCTRLA_ENABLE;
  
	  while( OSCCTRL->Dpll[0].DPLLSTATUS.bit.CLKRDY == 0 || OSCCTRL->Dpll[0].DPLLSTATUS.bit.LOCK == 0 );
  
	  //PLL1 is 100MHz
	  GCLK->PCHCTRL[OSCCTRL_GCLK_ID_FDPLL1].reg = (1 << GCLK_PCHCTRL_CHEN_Pos) | GCLK_PCHCTRL_GEN(GCLK_PCHCTRL_GEN_GCLK5_Val);
  
	  OSCCTRL->Dpll[1].DPLLRATIO.reg = OSCCTRL_DPLLRATIO_LDRFRAC(0x00) | OSCCTRL_DPLLRATIO_LDR(99); //100 Mhz
  
	  while(OSCCTRL->Dpll[1].DPLLSYNCBUSY.bit.DPLLRATIO);
  
	  //MUST USE LBYPASS DUE TO BUG IN REV A OF SAMD51
	  OSCCTRL->Dpll[1].DPLLCTRLB.reg = OSCCTRL_DPLLCTRLB_REFCLK_GCLK | OSCCTRL_DPLLCTRLB_LBYPASS;
  
	  OSCCTRL->Dpll[1].DPLLCTRLA.reg = OSCCTRL_DPLLCTRLA_ENABLE;
  
	  while( OSCCTRL->Dpll[1].DPLLSTATUS.bit.CLKRDY == 0 || OSCCTRL->Dpll[1].DPLLSTATUS.bit.LOCK == 0 );
  
  
	  /* ------------------------------------------------------------------------
	  * Set up the peripheral clocks
	  */
  
	  //48MHZ CLOCK FOR USB AND STUFF
	  GCLK->GENCTRL[GENERIC_CLOCK_GENERATOR_48M].reg = GCLK_GENCTRL_SRC(GCLK_GENCTRL_SRC_DFLL_Val) |
		GCLK_GENCTRL_IDC |
		//GCLK_GENCTRL_OE |
		GCLK_GENCTRL_GENEN;
  
	  while ( GCLK->SYNCBUSY.reg & GENERIC_CLOCK_GENERATOR_48M_SYNC)
		{
		  /* Wait for synchronization */
		}
  
	  //100MHZ CLOCK FOR OTHER PERIPHERALS
	  GCLK->GENCTRL[GENERIC_CLOCK_GENERATOR_100M].reg = GCLK_GENCTRL_SRC(GCLK_GENCTRL_SRC_DPLL1_Val) |
		GCLK_GENCTRL_IDC |
		//GCLK_GENCTRL_OE |
		GCLK_GENCTRL_GENEN;
  
	  while ( GCLK->SYNCBUSY.reg & GENERIC_CLOCK_GENERATOR_100M_SYNC)
		{
		  /* Wait for synchronization */
		}
  
	  //12MHZ CLOCK FOR DAC
	  GCLK->GENCTRL[GENERIC_CLOCK_GENERATOR_12M].reg = GCLK_GENCTRL_SRC(GCLK_GENCTRL_SRC_DFLL_Val) |
		GCLK_GENCTRL_IDC |
		GCLK_GENCTRL_DIV(4) |
		//GCLK_GENCTRL_DIVSEL |
		//GCLK_GENCTRL_OE |
		GCLK_GENCTRL_GENEN;
  
	  while ( GCLK->SYNCBUSY.reg & GENERIC_CLOCK_GENERATOR_12M_SYNC)
		{
		  /* Wait for synchronization */
		}
  
	  /*---------------------------------------------------------------------
	   * Set up main clock
	   */
  
	  GCLK->GENCTRL[GENERIC_CLOCK_GENERATOR_MAIN].reg = GCLK_GENCTRL_SRC(MAIN_CLOCK_SOURCE) |
		GCLK_GENCTRL_IDC |
		//GCLK_GENCTRL_OE |
		GCLK_GENCTRL_GENEN;
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

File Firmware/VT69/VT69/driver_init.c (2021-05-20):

/*
 * Code generated from Atmel Start.
 *
 * This file will be overwritten when reconfiguring your Atmel Start project.
 * Please copy examples or other code you want to keep to a separate file
 * to avoid losing it when reconfiguring.
 */

#include "driver_init.h"
#include <peripheral_clk_config.h>
#include <utils.h>
#include <hal_init.h>

struct flash_descriptor FLASH_0;

struct usart_sync_descriptor USART_0;

struct usart_sync_descriptor TARGET_IO;

struct usart_sync_descriptor USART_1;

struct rand_sync_desc RAND_0;

struct wdt_descriptor WDT_0;

void EXTERNAL_IRQ_0_init(void)
{
	hri_gclk_write_PCHCTRL_reg(GCLK, EIC_GCLK_ID, CONF_GCLK_EIC_SRC | (1 << GCLK_PCHCTRL_CHEN_Pos));
	hri_mclk_set_APBAMASK_EIC_bit(MCLK);

	ext_irq_init();
}

void FLASH_0_CLOCK_init(void)
{

	hri_mclk_set_AHBMASK_NVMCTRL_bit(MCLK);
}

void FLASH_0_init(void)
{
	FLASH_0_CLOCK_init();
	flash_init(&FLASH_0, NVMCTRL);
}

void USART_0_PORT_init(void)
{

	gpio_set_pin_function(PA08, PINMUX_PA08C_SERCOM0_PAD0);

	gpio_set_pin_function(PA09, PINMUX_PA09C_SERCOM0_PAD1);
}

void USART_0_CLOCK_init(void)
{
	hri_gclk_write_PCHCTRL_reg(GCLK, SERCOM0_GCLK_ID_CORE, CONF_GCLK_SERCOM0_CORE_SRC | (1 << GCLK_PCHCTRL_CHEN_Pos));
	hri_gclk_write_PCHCTRL_reg(GCLK, SERCOM0_GCLK_ID_SLOW, CONF_GCLK_SERCOM0_SLOW_SRC | (1 << GCLK_PCHCTRL_CHEN_Pos));

	hri_mclk_set_APBAMASK_SERCOM0_bit(MCLK);
}

void USART_0_init(void)
{
	USART_0_CLOCK_init();
	usart_sync_init(&USART_0, SERCOM0, (void *)NULL);
	USART_0_PORT_init();
}

void TARGET_IO_PORT_init(void)
{

	gpio_set_pin_function(PA00, PINMUX_PA00D_SERCOM1_PAD0);

	gpio_set_pin_function(PA01, PINMUX_PA01D_SERCOM1_PAD1);
}

void TARGET_IO_CLOCK_init(void)
{
	hri_gclk_write_PCHCTRL_reg(GCLK, SERCOM1_GCLK_ID_CORE, CONF_GCLK_SERCOM1_CORE_SRC | (1 << GCLK_PCHCTRL_CHEN_Pos));
	hri_gclk_write_PCHCTRL_reg(GCLK, SERCOM1_GCLK_ID_SLOW, CONF_GCLK_SERCOM1_SLOW_SRC | (1 << GCLK_PCHCTRL_CHEN_Pos));

	hri_mclk_set_APBAMASK_SERCOM1_bit(MCLK);
}

void TARGET_IO_init(void)
{
	TARGET_IO_CLOCK_init();
	usart_sync_init(&TARGET_IO, SERCOM1, (void *)NULL);
	TARGET_IO_PORT_init();
}

void USART_1_PORT_init(void)
{

	gpio_set_pin_function(PA12, PINMUX_PA12C_SERCOM2_PAD0);

	gpio_set_pin_function(PA13, PINMUX_PA13C_SERCOM2_PAD1);
}

void USART_1_CLOCK_init(void)
{
	hri_gclk_write_PCHCTRL_reg(GCLK, SERCOM2_GCLK_ID_CORE, CONF_GCLK_SERCOM2_CORE_SRC | (1 << GCLK_PCHCTRL_CHEN_Pos));
	hri_gclk_write_PCHCTRL_reg(GCLK, SERCOM2_GCLK_ID_SLOW, CONF_GCLK_SERCOM2_SLOW_SRC | (1 << GCLK_PCHCTRL_CHEN_Pos));

	hri_mclk_set_APBBMASK_SERCOM2_bit(MCLK);
}

void USART_1_init(void)
{
	USART_1_CLOCK_init();
	usart_sync_init(&USART_1, SERCOM2, (void *)NULL);
	USART_1_PORT_init();
}

void delay_driver_init(void)
{
	delay_init(SysTick);
}

void RAND_0_CLOCK_init(void)
{
	hri_mclk_set_APBCMASK_TRNG_bit(MCLK);
}

void RAND_0_init(void)
{
	RAND_0_CLOCK_init();
	rand_sync_init(&RAND_0, TRNG);
}

void USB_0_PORT_init(void)
{

	gpio_set_pin_direction(PA24,
	                       // <y> Pin direction
	                       // <id> pad_direction
	                       // <GPIO_DIRECTION_OFF"> Off
	                       // <GPIO_DIRECTION_IN"> In
	                       // <GPIO_DIRECTION_OUT"> Out
	                       GPIO_DIRECTION_OUT);

	gpio_set_pin_level(PA24,
	                   // <y> Initial level
	                   // <id> pad_initial_level
	                   // <false"> Low
	                   // <true"> High
	                   false);

	gpio_set_pin_pull_mode(PA24,
	                       // <y> Pull configuration
	                       // <id> pad_pull_config
	                       // <GPIO_PULL_OFF"> Off
	                       // <GPIO_PULL_UP"> Pull-up
	                       // <GPIO_PULL_DOWN"> Pull-down
	                       GPIO_PULL_OFF);

	gpio_set_pin_function(PA24,
	                      // <y> Pin function
	                      // <id> pad_function
	                      // <i> Auto : use driver pinmux if signal is imported by driver, else turn off function
	                      // <PINMUX_PA24H_USB_DM"> Auto
	                      // <GPIO_PIN_FUNCTION_OFF"> Off
	                      // <GPIO_PIN_FUNCTION_A"> A
	                      // <GPIO_PIN_FUNCTION_B"> B
	                      // <GPIO_PIN_FUNCTION_C"> C
	                      // <GPIO_PIN_FUNCTION_D"> D
	                      // <GPIO_PIN_FUNCTION_E"> E
	                      // <GPIO_PIN_FUNCTION_F"> F
	                      // <GPIO_PIN_FUNCTION_G"> G
	                      // <GPIO_PIN_FUNCTION_H"> H
	                      // <GPIO_PIN_FUNCTION_I"> I
	                      // <GPIO_PIN_FUNCTION_J"> J
	                      // <GPIO_PIN_FUNCTION_K"> K
	                      // <GPIO_PIN_FUNCTION_L"> L
	                      // <GPIO_PIN_FUNCTION_M"> M
	                      // <GPIO_PIN_FUNCTION_N"> N
	                      PINMUX_PA24H_USB_DM);

	gpio_set_pin_direction(PA25,
	                       // <y> Pin direction
	                       // <id> pad_direction
	                       // <GPIO_DIRECTION_OFF"> Off
	                       // <GPIO_DIRECTION_IN"> In
	                       // <GPIO_DIRECTION_OUT"> Out
	                       GPIO_DIRECTION_OUT);

	gpio_set_pin_level(PA25,
	                   // <y> Initial level
	                   // <id> pad_initial_level
	                   // <false"> Low
	                   // <true"> High
	                   false);

	gpio_set_pin_pull_mode(PA25,
	                       // <y> Pull configuration
	                       // <id> pad_pull_config
	                       // <GPIO_PULL_OFF"> Off
	                       // <GPIO_PULL_UP"> Pull-up
	                       // <GPIO_PULL_DOWN"> Pull-down
	                       GPIO_PULL_OFF);

	gpio_set_pin_function(PA25,
	                      // <y> Pin function
	                      // <id> pad_function
	                      // <i> Auto : use driver pinmux if signal is imported by driver, else turn off function
	                      // <PINMUX_PA25H_USB_DP"> Auto
	                      // <GPIO_PIN_FUNCTION_OFF"> Off
	                      // <GPIO_PIN_FUNCTION_A"> A
	                      // <GPIO_PIN_FUNCTION_B"> B
	                      // <GPIO_PIN_FUNCTION_C"> C
	                      // <GPIO_PIN_FUNCTION_D"> D
	                      // <GPIO_PIN_FUNCTION_E"> E
	                      // <GPIO_PIN_FUNCTION_F"> F
	                      // <GPIO_PIN_FUNCTION_G"> G
	                      // <GPIO_PIN_FUNCTION_H"> H
	                      // <GPIO_PIN_FUNCTION_I"> I
	                      // <GPIO_PIN_FUNCTION_J"> J
	                      // <GPIO_PIN_FUNCTION_K"> K
	                      // <GPIO_PIN_FUNCTION_L"> L
	                      // <GPIO_PIN_FUNCTION_M"> M
	                      // <GPIO_PIN_FUNCTION_N"> N
	                      PINMUX_PA25H_USB_DP);
}
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

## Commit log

2019-03-03 Initial
    Added firmware, PCB design, PCB gerbers
    [Test Board.brd, Test Board.sch]
2019-03-03 Added Bezel STL
    [KeyboardSTL.stl]
2019-08-28 clean up
    [DumbBadge.brd, DumbBadge.sch, DumbBadgeButtonsOutline.dxf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]
2019-10-01 fixed dimensions
    [Bottom.stl, DumbBadgeFusion.brd, DumbBadgeFusion.sch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]
2019-10-11 Found a demux
    [DumbBadgeFusion.brd]
2019-11-12 beginning Firmware
    [ATSamD21JPinout.csv, DumbBadgeFusion.brd, DumbBadgeFusion.sch]
2019-11-24 dear god
    [ATSamD21JPinout.csv]
2019-12-28 power supply
    [DumbBadgeFusion.brd, DumbBadgeFusion.sch]
2019-12-28 more power
    [DumbBadgeFusion.brd, DumbBadgeFusion.sch]
2019-12-30 added FPC conn
    [DumbBadgeFusion.brd, DumbBadgeFusion.sch]
2019-12-31 updated something
    [DumbBadgeFusion.brd, DumbBadgeFusion.sch]
2020-01-01 fixing power supply
    [DumbBadgeFusion.brd, DumbBadgeFusion.sch]
2020-01-01 more power supply
    [DumbBadgeFusion.brd, DumbBadgeFusion.sch]
2020-01-04 redid and prettified power supply
    [DumbBadgeFusion.brd, DumbBadgeFusion.sch]
2020-01-05 lots of updating
    [DumbBadgeFusion.brd, DumbBadgeFusion.sch]
2020-01-08 modified models
    [Bottom.stl, DumbBadgeFusion.brd, DumbBadgeFusion.sch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]
2020-01-08 fixed hole for fpc
    [DumbBadgeFusion.brd]
2020-01-10 got the display working
    [DumbBadgeFusion.brd]
2020-01-27 included qwertyembedded work
    [DumbBadgeFusion.brd, DumbBadgeFusion.sch]
2020-02-11 Fix swap and shift
    [main.c]
2020-02-24 TWO UARTS WORKING
2020-02-25 updated mechanical
    [Bottom.stl, DumbBadgePlasticv30Bottom.stl, DumbBadgePlasticv30Top.stl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]
2020-02-26 ratsnestnothing to do
    [DumbBadgeFusion.brd, DumbBadgeFusion.sch]
2020-02-26 Need to do the keyboard now
    [DumbBadge.brd, DumbBadge.sch, DumbBadgeFusion.brd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]
2020-02-26 removed keyboard matrix
    [DumbBadgeFusion.brd]
2020-02-28 almost done with keyboard
    [DumbBadgeFusion.brd, DumbBadgeFusion.sch]
2020-03-01 ratsnest nothing to do
    [DumbBadgeFusion.brd]
2020-03-03 Fixed a little bit
    [DumbBadgeFusion.brd]
2020-03-03 updated part names
    [DumbBadgeFusion.brd, DumbBadgeFusion.sch]
2020-03-05 Change to BOM, Macrofab order 2
    [DumbBadgeBOM.csv, DumbBadgeFusion.brd, DumbBadgeFusion.sch]
2020-03-05 more stuff
    [DumbBadgeBOM.csv, DumbBadgeFusion.brd, DumbBadgeFusion.sch]
2020-03-06 created keyboard standalone, improved schematics
    [DumbBadgeFusion.brd, DumbBadgeFusion.sch, Keyboard.brd]
2020-03-06 Fixed footprint for ESD, D1
    [DumbBadgeFusion.brd, DumbBadgeFusion.sch]
2020-03-07 Cleaned up
    [ATSamD21JPinout.csv, DumbBadgeBOM.csv, DumbBadgeFusion.brd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]
2020-03-08 stuff changed
    [DumbBadgeFusion.brd, DumbBadgeFusion.sch]
2020-03-09 Gassée aint got nothing on me
    [DumbBadgeBOM.csv]
2020-03-13 changed board hole to 0.25
2020-04-11 Getting stuff working
    [DumbBadgeFusion.brd, DumbBadgeFusion.sch]
2020-04-11 Added PDF schematics
2020-04-11 create schematic pdf
2020-04-14 Revert to working proto
    [main.c]
2020-04-15 update, fixed DIR enable on IC3
    [DumbBadgeFusion.brd]
2020-04-16 added tag connect
    [DumbBadgeFusion.sch]
2020-04-17 fixed Max3232
    [DumbBadgeFusion.brd]
2020-04-17 nother update
    [DumbBadgeFusion.brd, DumbBadgeFusion.sch]
2020-04-17 added bigger switch
    [DumbBadgeFusion.brd, DumbBadgeFusion.sch]
2020-04-18 starting rerouting
    [DumbBadgeFusion.brd, DumbBadgeFusion.sch]
2020-04-18 fixed FPC distance
    [DumbBadgeFusion.brd]
2020-04-18 routed LCD bus
    [DumbBadgeFusion.brd, DumbBadgeFusion.sch]
2020-04-19 might be done?
    [DumbBadgeFusion.brd]
2020-04-19 moved +24V gen, cleanup
    [DumbBadgeFusion.brd]
2020-04-19 slight update
    [DumbBadgeFusion.brd]
2020-04-20 fuck it, ship it
    [DumbBadgeFusion.brd]
2020-04-22 updated STLs
    [Bottom.stl, DumbBadgePlasticv30Bottom.stl, DumbBadgePlasticv30Top.stl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]
2020-04-24 added the 0.1" UART headers and level converters
    [DumbBadgeFusion.brd, DumbBadgeFusion.sch]
2020-04-24 fixed UART drivers, added 2v5
    [DumbBadgeFusion.brd, DumbBadgeFusion.sch]
2020-05-24 made a tiny level shifter
    [LevelShifter.brd, LevelShifter.sch]
2020-06-05 There's a memory leak in here somewhere
    [DumbBadgeFusion.sch]
2020-06-06 changed ADC; now all keys work
2020-06-06 SINGLE BOARD COMPUTER autodetect works
2020-06-08 kinda sorta works
    [DumbBadgeFusion.brd]
2020-06-19 fixed test keyboard
    [KeyMapping.csv, Keyboard.brd]
2020-07-02 Created BaudBox
    [Blank.brd, Blank.sch, ESP12.brd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]
2020-07-05 added camera mount adapter / extension boards
    [CameraMountAdapter.stl, MCUDemoBoard.brd, MCUDemoBoard.dxf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]
2020-07-07 slightly improved
    [CameraMountAdapter.stl, CameraMountAdapterBack.stl]
2020-07-16 MCU demo board confirmed working
2020-08-02 Revert "thing"
    This reverts commit a51b307f2a664d50ead796a9f4cdda2b25c7fdbb.
    [Keyboard.dxf, Keyboard.stl, KeyboardandMCU.stl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]
2020-08-02 Revert "Revert "thing""
    This reverts commit 8c9650857222a62df8ffb5667e0554840ec779a4.
    [Keyboard.dxf, Keyboard.stl, KeyboardandMCU.stl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]
2020-08-31 Added embiggened keyboard, do the layout for that
    [EmbiggenedKeyboard.brd, EmbiggenedKeyboard.sch]
2020-09-18 This doesn't fix the cursor problem, but it's better
    redid everything so pixel 0,0 is in the upper left
    [EmbiggenedKeyboard.sch]
2020-09-29 It should work, but it doesn't
    [globals.h]
2020-10-13 still doesn't work, but it's better than it was
    [main.c]
2020-10-13 cursor works, no warnings or errors
    [globals.h]
2020-10-16 changed MCU test board for FPC cable, other mods, moved test keyboard
    [Keyboard.brd, Keyboard.dxf, Keyboard.sch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]
2020-10-16 added uart.h uart.c
2020-10-29 I don't know what the fuck I'm donig what the fuck
    [DumbBadgeFusion.brd, TestKeyboardAdapter.brd, TestKeyboardAdapter.sch]
2020-11-13 Updated ESP expansion; now teledildonics and swapped TX and RX lines
    [ESP12.brd, ESP12.sch]
2020-11-24 massive improvement in random seeding
    XORing temp sensor adc with system_gclk_gen_get_hz
2020-12-08 fixed the screen scrolling bug
    [main.c]
2021-02-17 fixed character duplication on escstate
    [DumbBadgeFusion.brd]
2021-03-19 escape code handling
    [ESP12.brd]
2021-04-02 finalized SamD51 Board
    [DumbBadgeFusion.brd, DumbBadgeFusion.sch]
2021-04-02 fixed gerbers, updated BOM
    [DumbBadgeBOM.csv, DumbBadgeFusion.sch]
2021-05-07 script to tear apart esc codes
2021-05-20 Added SamD51 demo board; tried to get D51 software working
    [MCUDemoBoard.brd, MCUDemoBoard.sch]
2021-05-25 implemented Set Mode / Reset Mode, fixed HPV/ CUP
    [globals.h, main.c]
2021-06-04 fixed something in SGR
    [main.c]
2021-06-21 fixed some things, added stl
    [atmel_start_pins.h]

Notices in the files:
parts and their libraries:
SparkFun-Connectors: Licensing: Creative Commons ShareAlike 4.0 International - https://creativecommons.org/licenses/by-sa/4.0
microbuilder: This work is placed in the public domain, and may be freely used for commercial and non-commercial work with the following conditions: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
